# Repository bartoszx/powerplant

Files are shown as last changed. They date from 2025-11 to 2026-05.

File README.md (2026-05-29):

# POWERPANEL

_Opis funkcjonalny systemu — retro‑analogowy interfejs do Home Assistanta._

 

<p align="center">
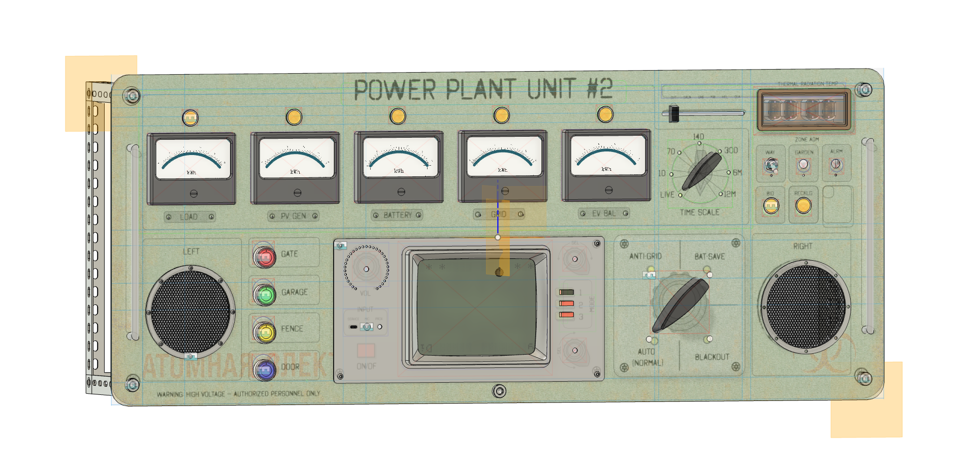
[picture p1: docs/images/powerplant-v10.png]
PowerPanel – wizualizacja
  
  <a href="docs/images/clean-wiz.JPEG">PowerPanel – czysta wizualizacja</a>
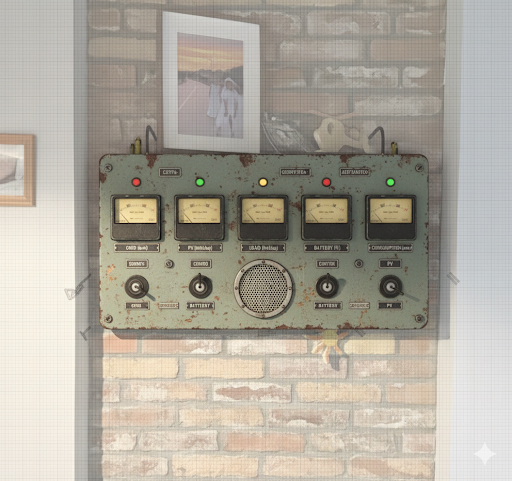
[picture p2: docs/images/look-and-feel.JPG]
PowerPanel – look & feel
  
</p>

_Kliknij, aby powiększyć. Wymiary panelu: 108 × 44 cm._ 

### Spis treści
- [1. Cel i koncepcja projektu](#1-cel-i-koncepcja-projektu)
- [2. Architektura i główne sekcje panelu](#2-architektura-i-główne-sekcje-panelu)
  - [2.1 Płyta główna (Main Board)](#21-płyta-główna-main-board)
  - [2.2 Moduły zewnętrzne](#22-moduły-zewnętrzne)
- [3. Mechanika i interfejs użytkownika](#3-mechanika-i-interfejs-użytkownika)
  - [3.1 Mierniki (sekcja)](#31-mierniki-sekcja)
- [4. Bloki funkcjonalne](#4-bloki-funkcjonalne)
  - [4.1 BLK_METER_ANALOG](#41-blk_meter_analog)
  - [4.2 BLK_METER_LED](#42-blk_meter_led)
  - [4.3 BLK_SWITCHES](#43-blk_switches)
  - [4.4 BLK_CONSOLE](#44-blk_console)
  - [4.5 BLK_SWITCH_LED](#45-blk_switch_led)
- [5. Komunikacja i zasilanie](#5-komunikacja-i-zasilanie)
- [6. Mechanika i ergonomia](#6-mechanika-i-ergonomia)
- [7. Uwagi konstrukcyjne](#7-uwagi-konstrukcyjne)
- [8. Podsumowanie](#8-podsumowanie)
- [9. Pliki schematów i PCB](#9-pliki-schematów-i-pcb)

---

## 1. Cel i koncepcja projektu
PowerPanel to fizyczna interpretacja możliwości systemu Home Assistant — 
czyli materialny, retro-analogowy interfejs do cyfrowego świata automatyki domowej.  

Nie jest to tylko panel energetyczny, ale wielosekcyjny moduł kontrolny i wizualizacyjny,
który odwzorowuje najważniejsze funkcje systemu HA w postaci fizycznych mierników, przycisków, 
przełączników, enkoderów i wskaźników świetlnych.

Celem jest uzyskanie wrażenia „żywego pulpitu sterowniczego” — 
panelu, który reaguje w czasie rzeczywistym na dane z Home Assistanta: energię, temperatury, stany stref, 
tryby pracy, alarmy, a także pozwala na bezpośrednią interakcję z systemem przez dotyk, pokrętła i przełączniki.

Całość utrzymana w stylistyce retro-industrialnej: 
mierniki URAL, bakelitowe przełączniki krzywkowe, suwakowe selektory, 
oraz matowy ekran LCD w stylu terminalowym, wpisujący się w analogowy klimat.

## 2. Architektura i główne sekcje panelu
System składa się z jednej płyty głównej (Main Board) i zestawu płytek peryferyjnych połączonych taśmami IDC.

### 2.1 Płyta główna (Main Board)
Zawiera wszystkie układy logiczne, analogowe i interfejsowe:
- ekspandery MCP23017 (wejścia, przyciski, enkodery),
- przetwornik DAC MCP4728 (sterowanie wskazówkami),
- bufory 74AHCT125 (3.3V → 5V dla WS2812),
- sterowniki ULN2803A (lampki i podświetlenia 12V),
- wzmacniacze LM358 (sterowniki prądowe wskaźników),
- złącza IDC dla modułów zewnętrznych.

<p align="center">
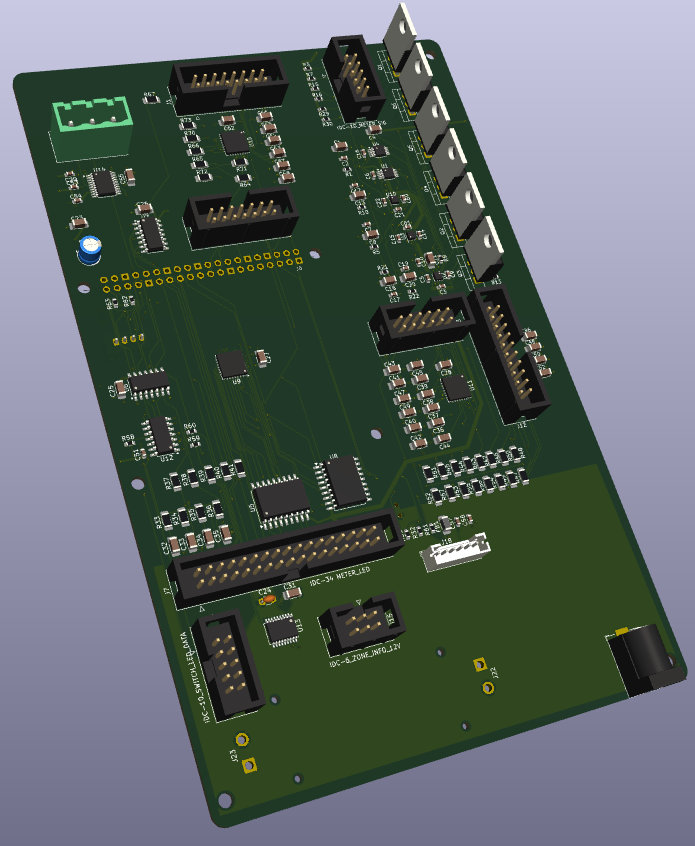
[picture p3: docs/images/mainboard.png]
Płyta główna – wizualizacja 3D
  
</p>

_Wizualizacja 3D płyty głównej (KiCad)._ 

Serce systemu stanowi Raspberry Pi 5, zamontowane bezpośrednio na płycie głównej (formą zbliżone do HAT), zapewniając komunikację, logikę i integrację z Home Assistantem.

Zasilanie:
- 12 V – sekcja mocy i lampek,
- 5 V – LED i DAC,
- 3.3 V – logika i magistrala I²C.
Masę podzielono na GND i GNDPWR (łączone w jednym punkcie).

### 2.2 Moduły zewnętrzne
- **NIXIE BOARD** – sterowanie lampami IN-14 (SPI, wysokonapięciowe).
- **METER PANEL** – z miernikami URAL i podświetleniem LED WS2812.
- **SWITCH PANEL** – sekcja przełączników trybów i zakresów czasowych.
- **CONSOLE PANEL** – centralny moduł z retro-ekranem LCD, enkoderami i kontrolkami.
- **ZONE ADM PANEL** – sekcja administracyjna stref (WAY / GARDEN / ALARM / OPEN).
- **INFO LED BOARD** – lampki 12 V (BIO, REC, OPEN, statusy).

Każdy moduł łączy się z płytą główną przez złącza IDC (10–34 pin).

## 3. Mechanika i interfejs użytkownika
Panel został podzielony na kilka stref funkcjonalnych, rozmieszczonych ergonomicznie na froncie obudowy:

- **Sekcja mierników (górna)** – pięć wskaźników URAL, 
  każdy z osobnym kanałem DAC i LED-podświetleniem.  
  Powyżej nich znajduje się przełącznik krzywkowy pozwalający zmieniać **skalę czasu** (LIVE / 1D / 7D / 14D / 1M / 6M / 12M).

- **Sekcja ZONE ADM (lewa dolna)** – przyciski i lampki strefowe, 
  np. WAY, GARDEN, ALARM, OPEN_PLACE.  
  Każda lampka 12 V jest sterowana z ULN2803A, a przycisk raportuje stan do HA przez I²C.

- **Centralna sekcja sterowania** – retro ekran LCD (terminalowy, tekstowy) 
  pokazujący status systemu i parametry; obok pokrętło **głośności (ENC_VOL)** z ring-LED, 
  przyciski **MODE_A/B/C** (zmiana trybu HA), oraz **przełącznik INPUT/OUTPUT**.

- **Sekcja energetyczna (prawa dolna)** – przełącznik krzywkowy głównego obiegu energetycznego (np. GRID / BAT / ISLAND),
  kontrolki statusu ładowania, oraz wskaźnik prądu zasilania głównego.

- **Selektor temperatury (prawy górny)** – przełącznik suwakowy wybierający, 
  które pomieszczenie ma być aktualnie wskazywane na mierniku temperatury (OUTDOOR / SALON / GAB / MIB / HEL / OLA).

Każdy element panelu ma fizyczne sprzężenie zwrotne: ruch wskazówki, światło LED, dźwięk enkodera, klik przełącznika.  
To czyni PowerPanel prawdziwie materialnym interfejsem Home Assistanta.

### 3.1 Mierniki (sekcja)
<p align="center">
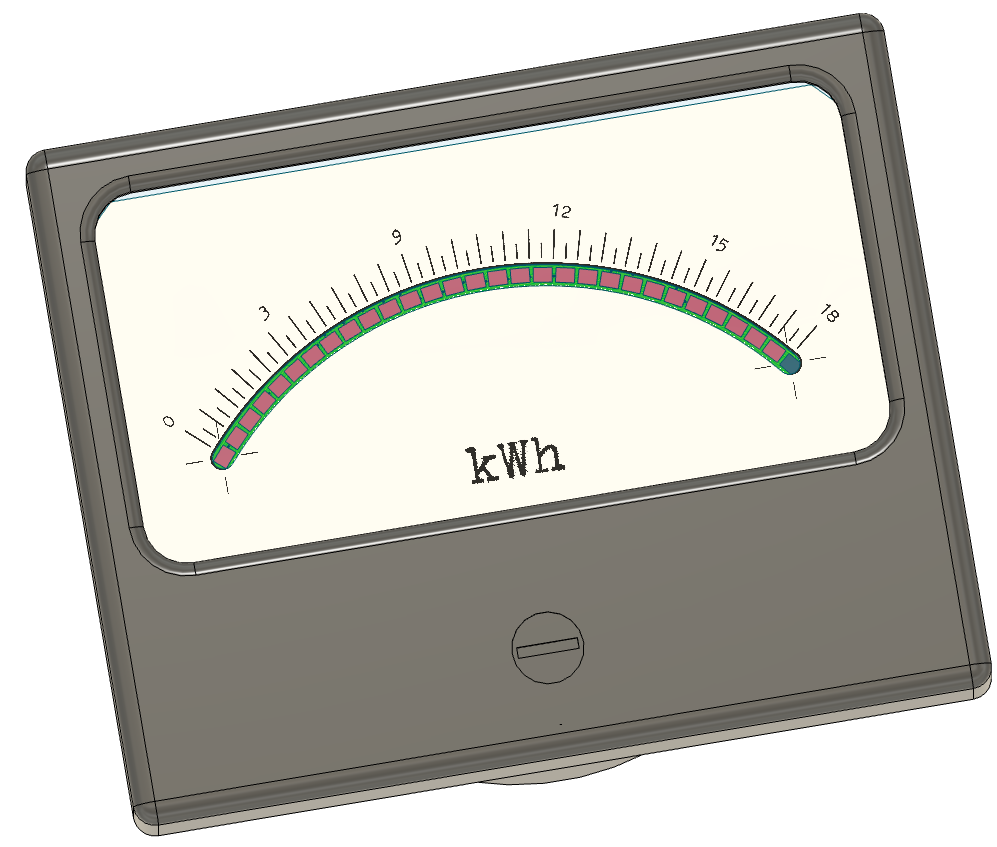
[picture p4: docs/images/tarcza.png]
Tarcza miernika
  
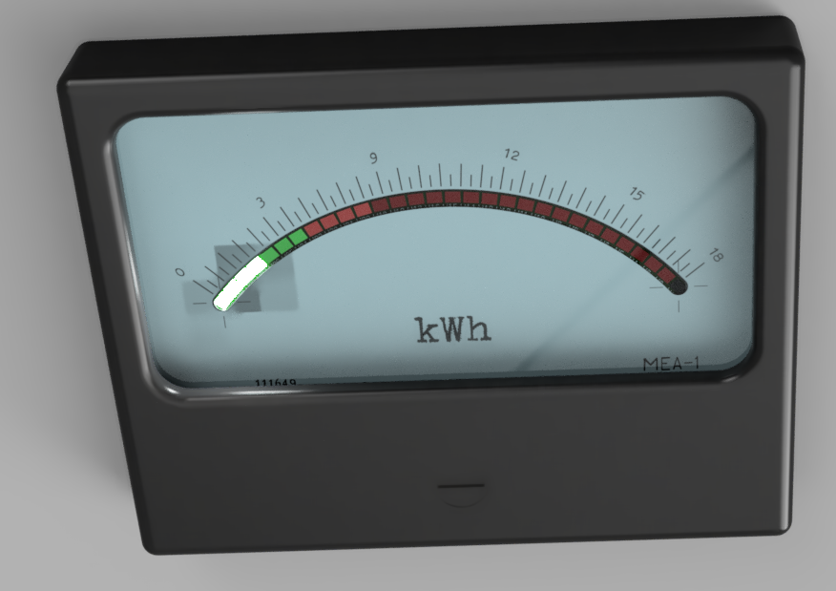
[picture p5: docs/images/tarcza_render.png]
Render sekcji
  
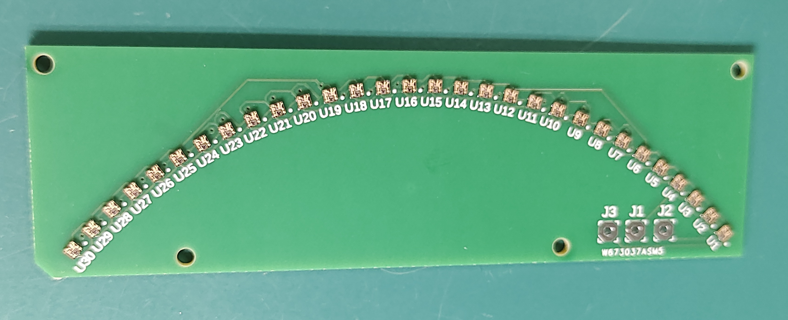
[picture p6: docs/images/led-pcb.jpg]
PCB 30 micro‑LED
  
  
</p>

_Tarcza, render sekcji i płytka z 30 micro‑LED — kliknij, aby powiększyć._

Na schemacie wyjścia prowadzące do poszczególnych mierników oznaczone są ich pierwotnymi parametrami (np. „2A”, „25mA”). Oznaczenia te służą pamięci i kalibracji podczas strojenia układu.

Każdy miernik, poza podstawowym działaniem pomiarowym, został zmodyfikowany:
- pod główną skalą umieszczono 30 programowalnych micro‑LEDów, pozwalających tworzyć efekty świetlne i subtelne wskazania kontekstowe,
- dodatkowy LED podświetla tarczę, poprawiając czytelność w słabym oświetleniu.

## 4. Bloki funkcjonalne

### 4.1 BLK_METER_ANALOG
Sterowanie pięcioma miernikami URAL.  
Układy: MCP4728 + LM358 + tranzystory 2N2222A.  
Każdy kanał DAC generuje napięcie (0–5 V) → LM358 → tranzystor NPN → cewka miernika.  
Filtry RC (100 nF + 10 kΩ) wygładzają wskazanie.  
Zasilanie 5 V, masa GNDPWR.  
Kanały: SENSE_A–E (MTR1–MTR5).

---

### 4.2 BLK_METER_LED
Sterowanie LED WS2812 i przyciskami 12 V w sekcji mierników i przycisków.  
Układy: MCP23017, ULN2803A ×2, 74AHCT125 ×2.  
Port A MCP23017 steruje ULN2803A (OUT_Mx_BL, URAL).  
Port B obsługuje przyciski i kontrolki (BTN_GATE, GARAGE, DOOR itd.).  
Bufory 74AHCT125 translatują sygnały LED 3.3V → 5V (MTR1–MTR5).  
Rezystory 68 Ω w szereg z liniami danych.  
Lampki 12 V sterowane z ULN2803A (open collector).  
GND i GNDPWR łączone w jednym punkcie.

---

### 4.3 BLK_SWITCHES
Sekcja 12 przełączników (tryby + zakresy) i 4 przyciski ZONE ADM.  
Układ: MCP23017 @ 0x21.  
Wejścia z pull-up 10 kΩ, C=100 nF do GND (debounce).  
Złącza:  
- IDC-20_SWITCH_BUS – tryby pracy (AUTO, BAT-SAVE, BLACKOUT, itp.)  
- IDC-12_SWITCH_ZONE_BUS – strefy (WAY, GARDEN, ALARM, OPEN)  
Stany czytane przez I²C.

---

### 4.4 BLK_CONSOLE
Centralny panel z trzema enkoderami i przyciskami MODE.  
Układ: MCP23017 @ 0x23.  
Pull-up 10 kΩ + C=100 nF (debounce).  
Linia INT_CONSOLED (opcjonalne przerwanie).  
Złącze IDC-16_CONSOLE:  
- MODE_A/B/C – wybór trybów  
- ENC_VOL, ENC_TOP, ENC_BOTTOM – enkodery  
- VOL_RING_DATA – dane LED pierścienia  
- przyciski push – w osi enkoderów

---

### 4.5 BLK_SWITCH_LED
Buforowanie danych LED (74AHCT125) i sterowanie lampkami 12 V (ULN2803A).  
Złącza:  
- IDC-10_SWITCH_LED_DATA – LED WS2812  
- IDC-6_ZONE_INFO_12V – lampki BIO / REC / OPEN  
Sygnały 3.3V z RPi → bufory 5V → taśmy WS2812.  
Rezystory R58–R60 = 100 Ω.  
Wspólna masa GND↔GNDPWR.

---

## 5. Komunikacja i zasilanie
Magistrala I²C:
- MCP23017 (SWITCHES) – 0x21  
- MCP23017 (CONSOLE) – 0x23  
- MCP23017 (METER_LED) – 0x20  
- MCP4728 (METER_ANALOG) – 0x60  

Zasilanie:
- +12 V – lampki i przekaźniki  
- +5 V – LED WS2812, DAC  
- +3.3 V – logika i I²C  
- GND / GNDPWR – wspólny punkt (separacja prądów)

---

## 6. Mechanika i ergonomia
- Wskaźniki URAL – analogowe sprzężenie ruchu z DAC.  
- LED – efekt tła i animacje w rytmie danych HA.  
- Przyciski 12 V – kontrola stref / trybów.  
- Enkodery – głośność, tryby, ustawienia.  
- Krzywkowe i suwakowe selektory – wybór skali czasu, temperatury, źródła energii.  
- Retro LCD – dane systemowe i statusy HA.  

- Panel frontowy z blachy stalowej zostanie poddany kontrolowanemu procesowi postarzenia (patyna, przetarcia, delikatnie pordzewiałe krawędzie), aby uzyskać wygląd starego, przemysłowego urządzenia.

Każdy element ma bezpośrednią funkcję w HA i wizualne potwierdzenie akcji.

---

## 7. Uwagi konstrukcyjne
- Separacja GND / GNDPWR.  
- Stitching vias między planami mas.  
- 100 nF przy każdym układzie.  
- Rezystory szeregowe 68–100 Ω przy WS2812.  
- C = 1000 µF przy zasilaniu LED.  
- LM358 i MCP4728 zasilane z 5 V (z odniesieniem do GNDPWR).  
- Bufory 74AHCT125 – VCC = 5 V, Vih ≥ 2 V.

---

## 8. Podsumowanie
PowerPanel to fizyczny interfejs Home Assistanta — 
łączący dane z automatyki, energii, stref, mediów i systemów bezpieczeństwa w jednym, dotykalnym pulpicie.

Zawiera:
- 5 analogowych mierników URAL (DAC-sterowane),
- 3 enkodery + ring LED,
- 20+ LED WS2812,
- 20 przycisków i przełączników,
- kontrolki 12 V,
- wyświetlacz LCD retro,
- oraz krzywkowe i suwakowe selektory trybów.

Stanowi pomost między cyfrowym systemem automatyki a fizycznym światem.

---

## 9. Pliki schematów i PCB

**Źródło prawdy (source of truth)** dla hardware'u: **`hardware/pcb/powerplant.kicad_sch`**.  
Ten plik może się aktualizować; dokumentacja, konfiguracja i kod powinny być z nim zsynchronizowane.

Pliki KiCad znajdują się w katalogu `hardware/pcb`:

- Główne pliki projektu: `hardware/pcb/powerplant.kicad_sch`, `hardware/pcb/powerplant.kicad_pcb`
- Schematy bloków: 
  - `hardware/pcb/BLK_BUTTONS.kicad_sch`
  - `hardware/pcb/BLK_CONSOLE.kicad_sch`
  - `hardware/pcb/BLK_METER_LED.kicad_sch`
  - `hardware/pcb/BLK_SWITCH_LED.kicad_sch`
  - `hardware/pcb/BLK_SWITCHES.kicad_sch`

Pełne drzewo plików sprzętowych: `hardware/pcb/`.

**Moduł sterowania miernikami** (osobny projekt KiCad, pliki w Dropbox: `kicad/powerplant/modul-miernikow.*`):

- Opis schematu (weryfikacja MCP): [`doc/modul-miernikow-opis-schematu.md`](doc/modul-miernikow-opis-schematu.md)
- Wklejka na schemat KiCad: [`doc/modul-miernikow-wklejka-schemat.txt`](doc/modul-miernikow-wklejka-schemat.txt)

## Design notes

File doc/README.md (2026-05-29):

# Dokumentacja modułu mierników

Katalog w repozytorium **powerplant** (`doc/`).

| Plik | Zastosowanie |
|---|---|
| [modul-miernikow-opis-schematu.md](modul-miernikow-opis-schematu.md) | Pełna dokumentacja (czytanie, review, git) |
| [modul-miernikow-wklejka-schemat.txt](modul-miernikow-wklejka-schemat.txt) | Skrót do wklejenia jako blok tekstu na schemacie KiCad |

**Pliki KiCad (źródło prawdy obwodu):**  
`~/Dropbox/kicad/powerplant/modul-miernikow.kicad_pro` (+ `.kicad_sch`, `.kicad_pcb`)

## Weryfikacja przez MCP (KiCAD MCP Server)

Opis obwodu w tych plikach jest uzgadniany z **rzeczywistym schematem** przy użyciu **Model Context Protocol** — serwera MCP podłączonego do KiCad (netlista, ERC/DRC, analiza połączeń).

**Protokół potwierdzania:**

1. Otwarcie / eksport netlisty z aktualnego `modul-miernikow.kicad_sch`.
2. Sprawdzenie połączeń sieci (J18, J1, U16, LM358, AO3400, 74AHCT125).
3. Uruchomienie ERC i DRC (`kicad-cli` lub narzędzia MCP).
4. Wynik weryfikacji wpisywany w sekcji *Weryfikacja MCP* w `modul-miernikow-opis-schematu.md`.

Przy kolejnych zmianach schematu — ponowna weryfikacja MCP i aktualizacja daty w opisie.

**Uwaga:** Stary blok tekstu na schemacie (MCP4728, 2N2222, URAL, GNDPWR) jest **nieważny** — zastąpić treścią z `modul-miernikow-wklejka-schemat.txt`.

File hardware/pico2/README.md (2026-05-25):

# Pico 2 – sterowanie MTR1_DATA z głównego RPi

Pico 2 odbiera komendy po UART od RPi i steruje linią **MTR1_DATA** (WS2812, 34 LEDy) na **GPIO6** oraz podświetleniem na GPIO11..15.

## Połączenia

| RPi (BCM) | Kierunek | Pico 2  | Opis |
|---|---|---|---|
| BCM 14 | TXD → | GPIO 1  | RX (we) |
| BCM 15 | RXD ← | GPIO 0  | TX (wy) |
| GND | | GND | wspólna masa|
| (opcjonalnie 3V3/5V) | | VSYS / VBUS | zasilanie Pico |

**Pico GPIO 6** → **MTR1_DATA** (wejście danych taśmy WS2812 przy mierniku 1).  
**Pico GPIO 11..15** → podświetlenie mierników 1..5 (J5 spare).

## 1. Wgranie MicroPython na Pico 2

1. Pobierz firmware MicroPython dla RP2040:  
   https://micropython.org/download/RPI_PICO2/
2. Przytrzymaj BOOTSEL na Pico, podłącz USB, puść BOOTSEL – pojawi się dysk **RPI-RP2**.
3. Skopiuj na ten dysk plik **`.uf2`** z archiwum – Pico zrestartuje się z MicroPythonem.

## 2. Wgranie programu (main.py)

- Przez **Thonny** (lub inny REPL / mpremote): połącz się z Pico 2 przez USB i wgraj plik **`main.py`** do katalogu głównego (root) urządzenia.
- Albo przez **mpremote** (po `pip install mpremote`):
  ```bash
  mpremote connect /dev/ttyACM0 cp hardware/pico2/main.py :main.py
  mpremote connect /dev/ttyACM0 reset
  ```
- Po wgraniu **main.py** Pico przy starcie uruchomi nasłuch UART i sterowanie LEDami.

## 3. Podłączenie do RPi (bez USB)

- Odłącz Pico od USB.
- Zasil Pico z RPi (3V3 lub 5V – według Twojej konfiguracji) i połącz:
  - RPi **BCM14 (TXD)** → Pico **GPIO1 (RX)**
  - RPi **BCM15 (RXD)** ← Pico **GPIO0 (TX)**
  - **GND** – wspólna masa.
- Włącz RPi; Pico startuje z **main.py** i czeka na dane UART.

## 4. Test z RPi

Na głównym RPi (w katalogu projektu):

```bash
pip install pyserial pyyaml
python3 scripts/test_mtr1_via_pico.py --ping    # test łączności
python3 scripts/test_mtr1_via_pico.py          # miganie 34 LEDów
python3 scripts/test_mtr1_via_pico.py --fill 255 0 0   # cały pasek na czerwono
```

Port UART w configu: **config/hardware.yaml** → **pico2.serial.port** (domyślnie `/dev/serial0`). Na RPi 5 często to `/dev/ttyAMA0` lub symlink `/dev/serial0`.

## Protokół UART (RPi → Pico)

- **0xFF** – ping; Pico odpowiada jednym bajtem **0xFF**.
- **0x01** + **102 bajty** (34 × RGB) – ustawienie kolorów 34 LEDów (łuk) i odświeżenie (show).
- **0x02** + **1 B maska** + **3 B R,G,B** – podświetlenie: maska bit0..4 = MTR1..5 (1=on), kolor z R,G,B. Np. `0x02 0x01 100 180 255` = MTR1, niebiski.
- **0x03** – wszystkie podświetlenia OFF.
- **0x04** + **2 B długość (big-endian)** + **body** – OTA: zapis body do `main.py` na Pico i `soft_reset()` (max 16 KB).

Baud: **115200**, 8N1.

## Kolory (RGB vs GRB)

Większość taśm WS2812 ma **kolejność GRB** na drucie. W **main.py**:
- **Backlight** (GPIO11..15) – zawsze zapis (G,R,B), żeby (255,0,0) z hosta dawało czerwony.
- **Strip łuk** (GPIO6) – stała **MTR1_STRIP_GRB** (domyślnie `True`): host wysyła (R,G,B), Pico zapisuje (G,R,B) do NeoPixel.

Jeśli kolory na łuku się nie zgadzają z tym, co wysyła host (np. czerwony świeci na zielono, lub różne płytki 4-LED zachowują się inaczej), sprawdź:
1. **MTR1_STRIP_GRB** w main.py – ustaw `False`, wgraj OTA i przetestuj. Część taśm to RGB.
2. Jedna fizyczna taśma na wszystkich miernikach – wtedy kolejność jest taka sama; jeśli łączysz różne moduły (np. inne wersje WS2812/SK6812), mogą mieć różny order (RGB/GRB/BGR) i wtedy trzeba osobnej konfiguracji per-pin albo ujednolicić hardware.

## 5. OTA – aktualizacja main.py przez UART (bez USB)

Po **jednorazowym** wgraniu `main.py` przez USB (p. 2) możesz później aktualizować firmware **przez UART** z RPi:

```bash
python3 scripts/ota_pico_main.py
```

Skrypt wysyła zawartość `hardware/pico2/main.py` komendą 0x04. Pico zapisuje ją do `main.py` i restartuje się. Port z configu: **config/hardware.yaml** → **pico2.serial.port**.

**Uwaga:** Pierwsze wgranie `main.py` musi być przez USB (Thonny lub `mpremote cp ... :main.py`), żeby na Pico był kod z obsługą OTA. Potem aktualizacje możesz robić tylko przez UART.

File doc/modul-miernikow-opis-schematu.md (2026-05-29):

# Moduł sterowania miernikami — opis schematu

**Projekt KiCad:** `modul-miernikow.kicad_pro`  
**Pliki KiCad:** `~/Dropbox/kicad/powerplant/`  
**Dokumentacja (git):** `powerplant/doc/` (ten katalog)  
**Skrót do schematu:** [modul-miernikow-wklejka-schemat.txt](modul-miernikow-wklejka-schemat.txt)

---

## Weryfikacja MCP (KiCAD MCP Server)

Ten dokument opisuje **aktualny schemat**, nie historyczny blok tekstu (MCP4728 / 2N2222 / URAL).

| Pole | Wartość |
|---|---|
| Metoda | Model Context Protocol — KiCAD MCP Server + `kicad-cli` |
| Źródło prawdy | `modul-miernikow.kicad_sch`, netlista, ERC/DRC |
| Zakres | Połączenia J18, J1, U16, LM358, AO3400, 74AHCT125; mapa DAC; brak zwarcia nazw sieci krytycznych |
| Ostatnia weryfikacja | 2026-05-25 |
| DRC | 0 naruszeń (`modul-miernikow.kicad_pcb`) |
| ERC | 12 ostrzeżeń (biblioteka LM358, etykiety ML vs `J_METER_PLUS_MINUS+`, global/local labels) — **0 błędów** |
| Potwierdzenie toru A | Wizualnie w KiCad zgodne z opisem poniżej (użytkownik) |

**Przy zmianie schematu:** ponów eksport netlisty, ERC/DRC przez MCP lub `kicad-cli`, zaktualizuj tabelę powyżej i [modul-miernikow-wklejka-schemat.txt](modul-miernikow-wklejka-schemat.txt).

---

## 1. Rola modułu

Moduł **nie** jest pojedynczym miernikiem. To **jedna płyta** obsługująca **wszystkie 5 mierników** oraz komunikująca się z **płytą główną** (RPi5, Pico, przetwornica buck).

Na każdy miernik wychodzi osobny przewód (GX8 → terminal → moduł miernika), agregowany na płytce modułu w złączu **IDC-34 (J1)**.

Każdy miernik ma:

- sterowanie wskazówką (cewka),
- zasilanie i sterowanie LEDów sekcji: **DATA_LIGHT**, **DATA_SCALE**, **DATA_MODE** (w schemacie sieci `MTR_KWH_*` / `GPIO_KWH_*`).

---

## 2. Architektura połączeń

```text
Płyta główna (RPi5, Pico, buck)
        │
        ├── J18 EDGE 2×12 ── +5V, +12V, GND, I2C_SDA/SCL, GPIO_LIGHT/SCALE/KWH
        │                      │
        │                      ▼
        │              [ moduł mierników ]
        │                 U16 DAC7578
        │                 U2,U3,U10 LM358 + Q7..Q12 AO3400
        │                 U1,U4..U7 74AHCT125
        │
        └── (masa wspólna z modułem)

        J1 IDC-34 ──► mierniki 1..5 (cewka + LED DATA + +5V/GND)
```

**Założenie dokumentacyjne:** wszystko, co jest na **J18**, ma kontynuację na płycie głównej (zasilanie, I²C, GPIO).

**J1** to wyłącznie **wyjście na wiązki mierników** w terenie.

---

## 3. Złącza

### J18 — `EDGE` (2×12, do płyty głównej)

| Pin J18 | Sieć | Funkcja |
|---|---|---|
| 1, 2 | +5V | Zasilanie logiki |
| 3, 4, 6, 24 | GND | Masa |
| 5 | +12V | Zasilanie toru analogowego (cewki) |
| 7 | I2C_SDA | → U16 DAC7578 |
| 8 | I2C_SCL | → U16 DAC7578 |
| 9 | GPIO_LIGHT_1 | → U1 (74AHCT) |
| 10 | GPIO_SCALE_1 | → U1 |
| 11 | GPIO_KWH_1 | → U1 |
| 12–23 | GPIO_* 2..5 | → U4, U5, U6, U7 |

### J1 — `IDC-34_METER_SIG_OUT` (2×17, do mierników)

Patrz sekcja 7 i plik [modul-miernikow-wklejka-schemat.txt](modul-miernikow-wklejka-schemat.txt).

**+12 V nie występuje na J1** — cewki zasilane z modułu przez rezystory limitujące od szyny +12 V (wejście +12 V z J18).

---

## 4. Układy scalone

| Ref | Typ | Ilość | Funkcja |
|-----|-----|---|---|
| U16 | DAC7578xPW | 1 | 8-kanałowy DAC, I²C, sterowanie napięciem torów wskazówki |
| U2, U3, U10 | LM358 | 3 | Wzmacniacze — po 2 kanały na układ |
| Q7–Q12 | AO3400A | 6 | N-MOSFET low-side, przełączanie zwrotu cewki |
| U1, U4, U5, U6, U7 | 74AHCT125 | 5 | Bufor 3-state, LED DATA → J1 |

**Nie używane:** MCP4728, tranzystory NPN 2N2222, ULN2803/URAL w tym module.

---

## 5. Tor analogowy — wskazówka

### Wzorzec (kanały A–E2)

```text
DAC7578 VOUTx
    │
    R 10 kΩ
    ├── VIN_FILT_x ──► (+) wejście LM358
    └── 4,7 µF + 100 nF ──► GND

LM358 (−) ◄── SENSE_x ◄── source AO3400
              └── C ~680 pF (między wyjściem opampa a SENSE)
              └── R_SENSE do GND (wartość zależna od kanału)

LM358 wyjście ── R 100 Ω ── bramka AO3400 (Rgate)
                      └── Rpd 100 kΩ do GND

+12 V ── Rlimit ──► J1 "+" (strona cewki w mierniku)
AO3400 drain ──► J1 zwrot ("-" / ML / MR)
```

### Mapowanie DAC → miernik

| Kanał | DAC U16 | Sieć filtra | MOSFET | J1 | Typ miernika |
|---|---|---|---|-----|---|
| A | VOUTA (4) | VIN_FILT_A | Q7 | 1 (+), 2 (−) | jednostronny, 25 µA |
| B | VOUTB (13) | VIN_FILT_B | Q8 | 3 (+), 4 (−) | jednostronny, 5 mA |
| C | VOUTC (5) | VIN_FILT_C | Q9 | 5 (+), 6 (−) | jednostronny, 1 A |
| D | VOUTD (12) | VIN_FILT_D | Q10 | 7 (+), 8 (−) | jednostronny, TBC |
| E1 (ML) | VOUTE (6) | VIN_FILT_E1 | Q11 | 9 (ML) | ± lewo |
| E2 (MR) | VOUTF (11) | VIN_FILT_E2 | Q12 | 10 (MR) | ± prawo |

- **ML** = Miernik Left  
- **MR** = Miernik Right  
- Na fragmencie schematu może występować też etykieta `J_METER_PLUS_MINUS+` — **ta sama sieć co ML** (ERC: unikać duplikacji nazw).

**Nieużywane wyjścia DAC:** VOUTG, VOUTH (NC).

**LDAC (U16 pin 1) → GND** — aktualizacja wyjść DAC bez osobnego strobe.  
**ADDR0 (U16 pin 2) → GND** — bit adresu I²C (pełny adres w datasheet + kod Pico).

### Rezystory SENSE (kalibracja)

| Kanał | RSENSE (do GND z SENSE) | Uwaga |
|---|---|---|
| A | 200 kΩ | bias / słaba pętla prądowa w klasycznym sensie |
| B | 140 kΩ | jw. |
| C | 500 Ω | |
| D | 200 kΩ | |
| E1, E2 | 820 Ω | sensowniejszy zwrot dla ± |

Kalibracja prądu cewki **per kanał** w firmware i przy bring-up.

### Miernik ± (środek wskazówki)

- **4 mierniki** — wychylenie jednostronne (A–D).  
- **1 miernik** — wychylenie **+ / −** od środka: osobno **ML** i **MR**, dwa kanały DAC i dwa MOSFETy.  
- R29, R30 = **10 Ω** do +12 V (inna skala niż Rlimit 100 kΩ na torach A–D).

---

## 6. Tor LED

```text
Pico GPIO (J18) → wejście 74AHCT125 → wyjście → R 68 Ω → J1 MTR_* → miernik
```

| Miernik | LIGHT | SCALE | MODE (KWH) |
|---|---|---|---|
| 1 | J1-11 | J1-12 | J1-13 |
| 2 | J1-14 | J1-15 | J1-16 |
| 3 | J1-17 | J1-18 | J1-19 |
| 4 | J1-20 | J1-21 | J1-22 |
| 5 | J1-23 | J1-24 | J1-25 |

Zasilanie LED w miernikach: **+5 V** (J1: 27, 29, 31, 33), **GND** (26, 28, 30, 32, 34).

### 74AHCT125 — OE i kierunek

- **VCC = 5 V**  
- Kierunek: **host → bufor → J1** (Pico na płycie głównej steruje wejściami A)  
- **OE aktywne LOW:** kanał 1 OE (pin 1) → +5 V (**wyłączony**); OE kanałów 2–4 → GND (**włączone**)  
- Nieużywane piny 2–3 (1A, 1Y) — `no_connect`

---

## 7. Pełna mapa J1 (IDC-34)

| Pin | Sieć | Opis |
|-----|---|---|
| 1 | J_METER_25uA+ | + cewka, kanał A |
| 2 | METER- | zwrot Q7 |
| 3 | J_METER_5mA+ | + cewka, kanał B |
| 4 | (zwrot Q8) | − cewka B |
| 5 | J_METER_1A+ | + cewka, kanał C |
| 6 | (zwrot Q9) | − cewka C |
| 7 | J_METER_TBC+ | + cewka, kanał D |
| 8 | (zwrot Q10) | − cewka D |
| 9 | ML / J_METER_PLUS_MINUS+ | + strona ± |
| 10 | MR | − strona ± (Q12) |
| 11–25 | MTR_LIGHT/SCALE/KWH 1..5 | LED po buforze |
| 26–34 | GND / +5V | zasilanie szynowe mierników |

---

## 8. Zasilanie i masa

| Szyna | Źródło | Konsumenci na module |
|---|---|---|
| +5V | J18 | DAC, 74AHCT, kondensatory odsprzęgania |
| +12V | J18 pin 5 | Rlimit cewek, LM358 (pin 8), kondensatory C3/C4… |
| GND | J18 + J1 | wspólna masa analog + cyfra |

**GNDPWR** — nie występuje; jedna sieć **GND**.

---

## 9. Odsprzęganie (skrót)

- Każdy kanał DAC: **10 kΩ + 4,7 µF + 100 nF** do GND.  
- +12 V: **100 nF + 10 µF** (C3, C4, …).  
- DAC U16 i 74AHCT: grupa kondensatorów przy **+5 V** (C16, C55, C56, C74–C83).  
- LM358: **~680 pF** między wyjściem a SENSE (stabilizacja pętli).

---

## 10. PCB (stan na dzień weryfikacji MCP)

- Wymiary płyty: ~121 × 68 mm  
- DRC: **0** naruszeń  
- Via: drill 0,3 mm / 0,6 mm — nadaje się do ręcznego przewlekania  
- **Test points:** TP1–TP14 na schemacie (sekcja poniżej); footprint `TestPoint_Pad_D1.0mm` — po **Update PCB** (F8)

### Test points (TP1–TP14)

Panel po lewej stronie schematu (etykieta „TEST POINTS”); footprint: `TestPoint:TestPoint_Pad_D1.0mm`.

| Ref | Sieć | Ref | Sieć |
|-----|---|-----|---|
| TP1 | VIN_FILT_A | TP8 | SENSE_B |
| TP2 | VIN_FILT_B | TP9 | SENSE_C |
| TP3 | VIN_FILT_C | TP10 | SENSE_D |
| TP4 | VIN_FILT_D | TP11 | SENSE_E1 |
| TP5 | VIN_FILT_E1 | TP12 | SENSE_E2 |
| TP6 | VIN_FILT_E2 | TP13 | +5V |
| TP7 | SENSE_A | TP14 | +12V |

---

## 11. Bring-up (po wytrawieniu płytki)

Kolejność pierwszego uruchomienia na stole:

1. Zasilanie J18 (+5 V, +12 V, GND) — bez zwarcia.  
2. I²C — wykrycie DAC7578, odczyt rejestru.  
3. Kanał A — mały kod DAC, pomiar `VIN_FILT_A`, opcjonalnie cewka / obciążenie zamiast miernika.  
4. Kanały B, C, D po kolei.  
5. ± ML / MR — osobno E1 i E2.  
6. Jedna linia LED (np. `MTR_LIGHT_1`).  
7. Podłączenie J1 → 5 mierników.

---

## 12. Historia zmian dokumentacji

| Data | Zmiana |
|---|---|
| 2026-05-25 | Utworzenie w `powerplant/doc/`; weryfikacja MCP; zastąpienie opisu MCP4728/URAL/NPN |
| 2026-05-25 | TP1–TP14 na schemacie (VIN_FILT, SENSE, +5V, +12V) |

---

## Powiązane pliki

- [README.md](README.md) — ten katalog  
- [modul-miernikow-wklejka-schemat.txt](modul-miernikow-wklejka-schemat.txt) — wklejka na schemat KiCad

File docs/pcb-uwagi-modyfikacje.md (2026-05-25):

# Uwagi i planowane modyfikacje PCB (BLK_METER_LED, złącza)

Plik zbiera wymagania i uwagi do kolejnej rewizji płytki / zmian w okablowaniu.

---

## 1. MCP23017 – adresy I²C i sterowanie 5 miernikami

**Problem:** Rozszerzacze I/O (MCP23017) mają ten sam adres I²C, przez co nie da się niezależnie sterować wszystkimi 5 miernikami.

**Wymaganie:** Zmienić podejście do MCP tak, aby:
- każdy miernik (MTR1..MTR5) mógł być sterowany osobno,
- na I²C były unikalne adresy (np. różne A0/A1/A2 lub osobne układy z różnymi adresami).

**Uwagi do projektu:** Sprawdzić schemat BLK_METER_LED – które MCP sterują OUT_Mx_BL / OUT_Mx_URAL; zaproponować nowy podział adresów (np. 0x20, 0x21, …) i ewentualnie dodatkowe piny adresowe na PCB.

---

## 2. Jedno złącze na obsługę wszystkich mierników (wskaźówka + LED)

**Problem:** Obecnie sygnały są rozbite na wiele złączy – wskaźówka (DAC/cewka) w jednym, dane LED (MTRx_DATA) w innym, podświetlenie (J5 spare) osobno itd.

**Wymaganie:** Jedno gniazdo (lub jeden zestaw złączy) do obsługi wszystkich mierników:
- wskaźówka (analog / DAC),
- LED (łuk / pasek WS2812),
- podświetlenie (WS2812),

tak aby jeden kabel / jedna wtyczka obsługiwała cały miernik (albo wszystkie mierniki z jednego, czytelnego złącza).

**Uwagi do projektu:** Zdefiniować pinout tego złącza (zasilanie, GND, DATA_WS2812, DAC/cewka, ewent. wspólne linie) i przenieść go na PCB zamiast rozproszonych J5/MTRx_DATA itd.

---

## 3. Podświetlenie miernika – z LED na programowalne (WS2812)

**Stan:** Podświetlenie miernika zostało zmienione ze zwykłego LED na taśmę/pasek programowalny (WS2812).

**Konsekwencje:**
- Sterowanie jest przez linię danych (np. Pico GPIO11..15 → J5 spare), nie przez proste ON/OFF z MCP (OUT_Mx_BL).
- W firmware (Pico `main.py`): BACKLIGHT_PINS = [11, 12, 13, 14, 15], BACKLIGHT_LED_COUNTS (np. 2, 2, 40, 40, 40).
- Na PCB: sygnały podświetlenia to MTRx_DATA (lub odpowiedniki na J5), buforowane 3.3 V → 5 V (74AHCT125), z rezystorami szeregowymi (np. 68 Ω).

**Uwagi do projektu:** W następnej wersji PCB:
- potwierdzić, że podświetlenie jest wyłącznie WS2812 (bez równoległego sterowania przez MCP OUT_Mx_BL, chyba że celowo zostawione jako enable),
- ewentualnie uprościć opis w schemacie („podświetlenie = WS2812”) i dopasować nazewnictwo netów/złączy.

---

## Podsumowanie

| # | Temat | Cel |
|---|---|-----|
| 1 | MCP23017 | Unikalne adresy I²C, sterowanie 5 miernikami |
| 2 | Złącza | Jedno gniazdo na miernik (wskaźówka + LED + podświetlenie) |
| 3 | Podświetlenie | Ujęcie w dokumentacji przejścia z LED na WS2812 |

---

*Ostatnia aktualizacja: na podstawie uwag użytkownika.*

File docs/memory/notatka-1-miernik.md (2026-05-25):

# 📝 MCP4728 + analogowe mierniki  
**Projekt:** POWERPLANT / smartgun  
**Data:** 2026-02-08  

---

## 1. Konfiguracja sprzętowa
- DAC: **MCP4728**
- Adres I²C: **stały 0x60**
- Brak pinów adresowych (A0/A1) → brak możliwości zmiany adresu
- Zasilanie DAC: **~5 V**
- Wyjścia:
  - **VOUTA–D → LM358 → IRLZ44N → cewka miernika → Rsense → GND**
- Liczba mierników: **5**
  - 4 obsługiwane przez MCP4728
  - 5-ty wymaga osobnego rozwiązania

---

## 2. Kluczowe ustalenia
### ❌ Zmiana adresu MCP4728
- Nie da się zmienić adresu:
  - software’owo
  - przez EEPROM
  - przez LDAC / General Call
- Adres **0x60 jest zaszyty w krzemie**
- Wariant użyty na PCB **nie posiada pinów A0/A1**

➡️ **Dwa MCP4728 na jednej magistrali I²C bez muxa są niemożliwe**

---

## 3. Problemy początkowe i ich przyczyna
### 3.1 Zapis do DAC
- Biblioteka `adafruit_mcp4728` działała poprawnie
- Własny skrypt nie działał, ponieważ:
  - używał `SMBus.write_i2c_block_data()`
  - MCP4728 **nie obsługuje SMBus block write**
- Układ wymaga **RAW I²C (`i2c_rdwr`)**

➡️ Rozwiązanie: użycie **surowego zapisu I²C**

---

### 3.2 Ograniczenie napięcia do ~2 V
- MCP4728 miał zapisane w EEPROM:
  - **VREF = internal 2.048 V**
  - **GAIN = x1**
- Tryb Fast Write **nie zmienia VREF/GAIN**

➡️ Rozwiązanie:
- użycie **Multi-Write Input Register (0x40)**
- ustawienie:
  - `VREF = internal`
  - `GAIN = x2`

➡️ Efekt:
- **pełna skala ~4.9 V na VOUT**

---

## 4. Finalna konfiguracja DAC (działająca)
- Skala: **0–4095**
- Konfiguracja:
  - `VREF = internal`
  - `GAIN = x2`
- Efektywne napięcie wyjściowe: **~0–5 V**
- Uznana jako konfiguracja docelowa

---

## 5. Diagnostyka toru miernika
### Punkty pomiarowe
- **VOUTA MCP4728**  
  - stabilne napięcie DC  
  - poprawna praca DAC
- **Wyjście do miernika (IDC-10)**  
  - skoki napięcia  
  - overshooty  
  - wartości > VREF

➡️ Jest to **normalne**, ponieważ:
- miernik = indukcyjność
- pętla: LM358 + MOSFET + cewka
- brak tłumienia powoduje oscylacje
- multimetr pokazuje wartości uśrednione

---

## 6. Wnioski sprzętowe
- DAC działa poprawnie
- Oprogramowanie działa poprawnie
- MOSFET (IRLZ44N) działa poprawnie
- Miernik reaguje

❗ Główny problem: **niestabilna pętla prądowa**

---

## 7. Zalecane poprawki hardware
1. **Dioda flyback** równolegle do cewki miernika  
   (np. 1N4148 / dioda Schottky)
2. **Kondensator filtrujący na SENSE_A → GND**
   - start: **100 nF**
   - w razie potrzeby: 220–470 nF
3. Opcjonalnie:
   - RC na Gate MOSFETa (np. 10–47 nF)

---

## 8. Zalecenia software
- Nie używać pełnej skali 0–4095
  - typowo: **0–600 / 0–1200**
- Wolne rampy:
  - `step = 5–10`
  - `delay = 20–30 ms`
- Miernik analogowy ma wolną mechanikę

---

## 9. Problem 5. miernika – decyzje architektoniczne
Ponieważ:
- MCP4728 ma **tylko jeden adres (0x60)**
- liczba mierników > liczba kanałów DAC

### Realne opcje:
1. ✅ **I²C multiplexer TCA9548A**
2. ✅ **PWM + filtr RC** dla 5-tego miernika
3. ❌ Zmiana adresu MCP4728 (niemożliwe)

---

## 10. Stan końcowy
- Układ działa poprawnie
- Skala DAC opanowana
- Przyczyna problemów zidentyfikowana
- Projekt gotowy do dalszej rozbudowy

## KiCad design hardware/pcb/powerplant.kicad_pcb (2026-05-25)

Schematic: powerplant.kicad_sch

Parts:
A1: RaspberryPi_Pico; RaspberryPi_Pico_Common_Unspecified
C1, C8, C11, C13, C18, C20: 4.7 µF; R_1206_3216Metric
C2, C3, C6, C7, C10, C12, C16, C17, C19, C59, C60, C61: 100 nF; C_0603_1608Metric
C4, C29: 10 µF; R_1206_3216Metric
C5, C9, C14, C15, C21, C22: 680 pF; C_0603_1608Metric
C53, C58: 1 µF; C_0603_1608Metric
C54: 4.7 µF; C_0603_1608Metric
FB2: FerriteBead 600 Ω @ 100 MHz; L_1206_3216Metric_Pad1.22x1.90mm_HandSolder
J2: J_AUX; JST_PH_B8B-PH-K_1x08_P2.00mm_Vertical
J3: VL53L0X; JST_PH_B4B-PH-K_1x04_P2.00mm_Vertical
J4: J_LCD_PWR; JST_PH_B2B-PH-K_1x02_P2.00mm_Vertical
J5: SPARE; JST_PH_B8B-PH-K_1x08_P2.00mm_Vertical
J6: RPi_GPIO; RPI_Hat_B_NOPCB
J16: 14_NIXIE_BUS; IDC-Header_2x07_P2.54mm_Vertical
J19: J_LIGHT; JST_PH_B4B-PH-K_1x04_P2.00mm_Vertical
J21: IDC-10_METER_SIG; IDC-Header_2x05_P2.54mm_Vertical
J22: J_IN; SolderWire-1sqmm_1x02_P5.4mm_D1.4mm_OD2.7mm
J23: J_OUT; SolderWire-1sqmm_1x02_P5.4mm_D1.4mm_OD2.7mm
J24: POWER IN 12V; BarrelJack_Horizontal
NT1: NetTie_2; NetTie-2_THT_Pad1.0mm
Q1, Q2, Q3, Q4, Q5, Q6: IRLZ44N; TO-220-3_Vertical
R1, R5, R9, R10, R21, R22: 10 kΩ; R_0603_1608Metric
R2, R6, R11, R12, R23, R24: 100 Ω; R_1206_3216Metric_Pad1.30x1.75mm_HandSolder
R3, R15: Rlimit 100 kΩ; R_0603_1608Metric
R4, R8, R13, R14, R25, R26: Rpd 100 kΩ; R_0603_1608Metric
R7: Rlimit 150 kΩ; R_0603_1608Metric
R16, R29, R30: Rlimit 10 Ω; R_0603_1608Metric
R17, R20: RSENSE 200 kΩ; R_0603_1608Metric
R18: RSENSE 140 kΩ; R_0603_1608Metric
R19: RSENSE 500 Ω; R_0603_1608Metric
R27, R28: RSENSE 820 Ω; R_0603_1608Metric
R62, R63: 4.7kΩ; R_0603_1608Metric
U1, U4: MCP4728; MSOP-10_3x3mm_P0.5mm
U2, U3, U10: LM358_DFN; DFN-8-1EP_2x2mm_P0.5mm_EP1.05x1.75mm
U14: TPS22917DBV; SOT-23-6

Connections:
+3.3V: FB2.1, J5.1, J6.1 (3.3V), R62.1, R63.1; also elsewhere on the board
+5V: A1.40 (VBUS), C6.2, C16.2, C53.2, J3.4, J6.2 (5V), J16.1, J16.10, J23.1, U1.1 (VDD), U4.1 (VDD), U14.1 (VIN); also elsewhere on the board
+12V: C3.1, C4.1, C29.1, C60.1, C61.1, J22.1, J24.1, R3.1, R7.1, R15.1, R16.1, R29.2, R30.2, U2.8 (V+), U3.8 (V+), U10.8 (V+); also elsewhere on the board
/AUX_I2S_LRCLK: J2.2, J6.35 (BCM19_MISO_PCM_FS)
/AUX_I2S_RX: J2.4, J6.38 (BCM20_MOSI_PCM_DI)
/AUX_I2S_TX: J2.3, J6.40 (BCM21_SCLK_PCM_DO)
/AUX_SCL: J2.6, J3.2, J6.5 (BCM3_SCL), J19.4, R62.2, U1.2 (SCL), U4.2 (SCL); also elsewhere on the board
/AUX_SDA: J2.5, J3.3, J6.3 (BCM2_SDA), J19.3, R63.2, U1.3 (SDA), U4.3 (SDA); also elsewhere on the board
/BLK_CONSOLE/INT_CONSOLE: J6.21 (BCM9_MISO); also elsewhere on the board
/BLK_METER_LED/CTRL_GARAGE_LED: J6.16 (BCM23); also elsewhere on the board
/BLK_METER_LED/CTRL_GATE_LED: J6.18 (BCM24); also elsewhere on the board
/BLK_METER_LED/GPIO_LED1: A1.9 (GPIO6); also elsewhere on the board
/BLK_METER_LED/GPIO_LED2: A1.10 (GPIO7); also elsewhere on the board
/BLK_METER_LED/GPIO_LED3: A1.11 (GPIO8); also elsewhere on the board
/BLK_METER_LED/GPIO_LED4: A1.12 (GPIO9); also elsewhere on the board
/BLK_METER_LED/GPIO_LED5: A1.14 (GPIO10); also elsewhere on the board
/BLK_METER_LED/GPIO_VOL_RING: A1.7 (GPIO5); also elsewhere on the board
/BLK_SWITCH_LED/LED_MODE_DATA_IN: A1.5 (GPIO3); also elsewhere on the board
/BLK_SWITCH_LED/LED_RANGE_DATA_IN: A1.4 (GPIO2); also elsewhere on the board
/BLK_SWITCH_LED/LED_TEMP_DATA_IN: A1.6 (GPIO4); also elsewhere on the board
/CTRL_INFO_BIO: J6.15 (BCM22); also elsewhere on the board
/CTRL_INFO_OPEN: J6.11 (BCM17); also elsewhere on the board
/CTRL_INFO_REC: J6.13 (BCM27); also elsewhere on the board
/GP0_TX_PICO: A1.1 (GPIO0), J6.10 (BCM15_RXD)
/GP1_RX_PICO: A1.2 (GPIO1), J6.8 (BCM14_TXD)
/GP11: A1.15 (GPIO11), J5.3
/GP12: A1.16 (GPIO12), J5.4
/GP13: A1.17 (GPIO13), J5.5
/GP14: A1.19 (GPIO14), J5.6
/GP15: A1.20 (GPIO15), J5.7
/GP16: A1.21 (GPIO16), J5.8
/J_METER_1A+: J21.5, R15.2
/J_METER_5mA+: J21.3, R7.2
/J_METER_25uA+: J21.1, R3.2
/J_METER_PLUS_MINUS+: J21.9, Q5.2 (D), R29.1
/J_METER_TBC+: J21.7, R16.2
/LCD_PWR_EN: J6.12 (BCM18_PCM_C), U14.3 (ON)
/METER-: J21.2, Q1.2 (D)
/MR: J21.10, Q6.2 (D), R30.1
/NIXIE_CS1: J6.24 (BCM8_CE0), J16.5
/NIXIE_CS2: J6.26 (BCM7_CE1), J16.6
/NIXIE_CS3: J6.22 (BCM25), J16.7
/NIXIE_CS4: J6.27 (BCM0_ID_SD), J16.8
/SENSE_A: C5.2, Q1.3 (S), R17.2, U2.2 (-)
/SENSE_B: C9.2, Q2.3 (S), R18.2, U2.6 (-)
/SENSE_C: C14.2, Q3.3 (S), R19.2, U3.2 (-)
/SENSE_D: C15.2, Q4.3 (S), R20.2, U3.6 (-)
/SENSE_E1: C21.2, Q5.3 (S), R27.1, U10.2 (-)
/SENSE_E2: C22.2, Q6.3 (S), R28.1, U10.6 (-)
/SPI_MOSI: J6.19 (BCM10_MOSI), J16.3
/SPI_SCLK: J6.23 (BCM11_SCLK), J16.4
/VIN_FILT_A: R1.1, U1.6 (VOUTA), U2.3 (+)
/VIN_FILT_B: R5.1, U1.7 (VOUTB), U2.5 (+)
/VIN_FILT_C: R9.1, U1.8 (VOUTC), U3.3 (+)
/VIN_FILT_D: R10.1, U1.9 (VOUTD), U3.5 (+)
/VIN_FILT_E1: R21.1, U4.6 (VOUTA), U10.3 (+)
/VIN_FILT_E2: R22.1, U4.7 (VOUTB), U10.5 (+)
GND: A1.3 (GND), A1.8 (GND), A1.13 (GND), A1.18 (GND), A1.23 (GND), A1.28 (GND), A1.38 (GND), C6.1, C16.1, C53.1, C54.2, C58.1, C59.1, J2.7, J3.1, J4.2, J5.2, J6.39 (GND), J16.2, J16.11, J16.12, J19.2, J23.2, NT1.1, U1.10 (VSS), U4.10 (VSS), U14.2 (GND); also elsewhere on the board
GNDPWR: C1.2, C2.1, C3.2, C4.2, C7.1, C8.2, C10.1, C11.2, C12.1, C13.2, C17.1, C18.2, C19.1, C20.2, C29.2, C60.2, C61.2, J22.2, J24.2, NT1.2, R4.2, R8.2, R13.2, R14.2, R17.1, R18.1, R19.1, R20.1, R25.1, R26.1, R27.2, R28.2, U2.4 (V-), U2.9 (PAD), U3.4 (V-), U3.9 (PAD), U10.4 (V-), U10.9 (PAD); also elsewhere on the board
unnamed: C1.1, C2.2, R1.2
unnamed: C5.1, R2.1, U2.1
unnamed: C7.2, C8.1, R5.2
unnamed: C9.1, R6.1, U2.7
unnamed: C10.2, C11.1, R9.2
unnamed: C12.2, C13.1, R10.2
unnamed: C14.1, R11.1, U3.1
unnamed: C15.1, R12.1, U3.7
unnamed: C17.2, C18.1, R21.2
unnamed: C19.2, C20.1, R22.2
unnamed: C21.1, R23.1, U10.1
unnamed: C22.1, R24.1, U10.7
unnamed: C54.1, J4.1, U14.6 (VOUT)
unnamed: C58.2, C59.2, FB2.2, J19.1
unnamed: J21.4, Q2.2 (D)
unnamed: J21.6, Q3.2 (D)
unnamed: J21.8, Q4.2 (D)
unnamed: Q1.1 (G), R2.2, R4.1
unnamed: Q2.1 (G), R6.2, R8.1
unnamed: Q3.1 (G), R11.2, R13.1
unnamed: Q4.1 (G), R12.2, R14.1
unnamed: Q5.1 (G), R23.2, R25.2
unnamed: Q6.1 (G), R24.2, R26.2

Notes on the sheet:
⚙️ BLK_METER_ANALOG - opis funkcjonalny ======================================== Sekcja: Tory sterowania i pomiaru wskaźników analogowych (5 kanałów VU / mA / wskazówki URAL) Układy główne: U3A-U3E, U10A-U10C - LM358 (wzmacniacze operacyjne) U1 - MCP4728 (4-kanałowy DAC I²C, 12-bit) Q1-Q5 - tranzys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
CZUJNIK SWIATLA
NIXIE zew board https://github.com/dekuNukem/exixe po SPI

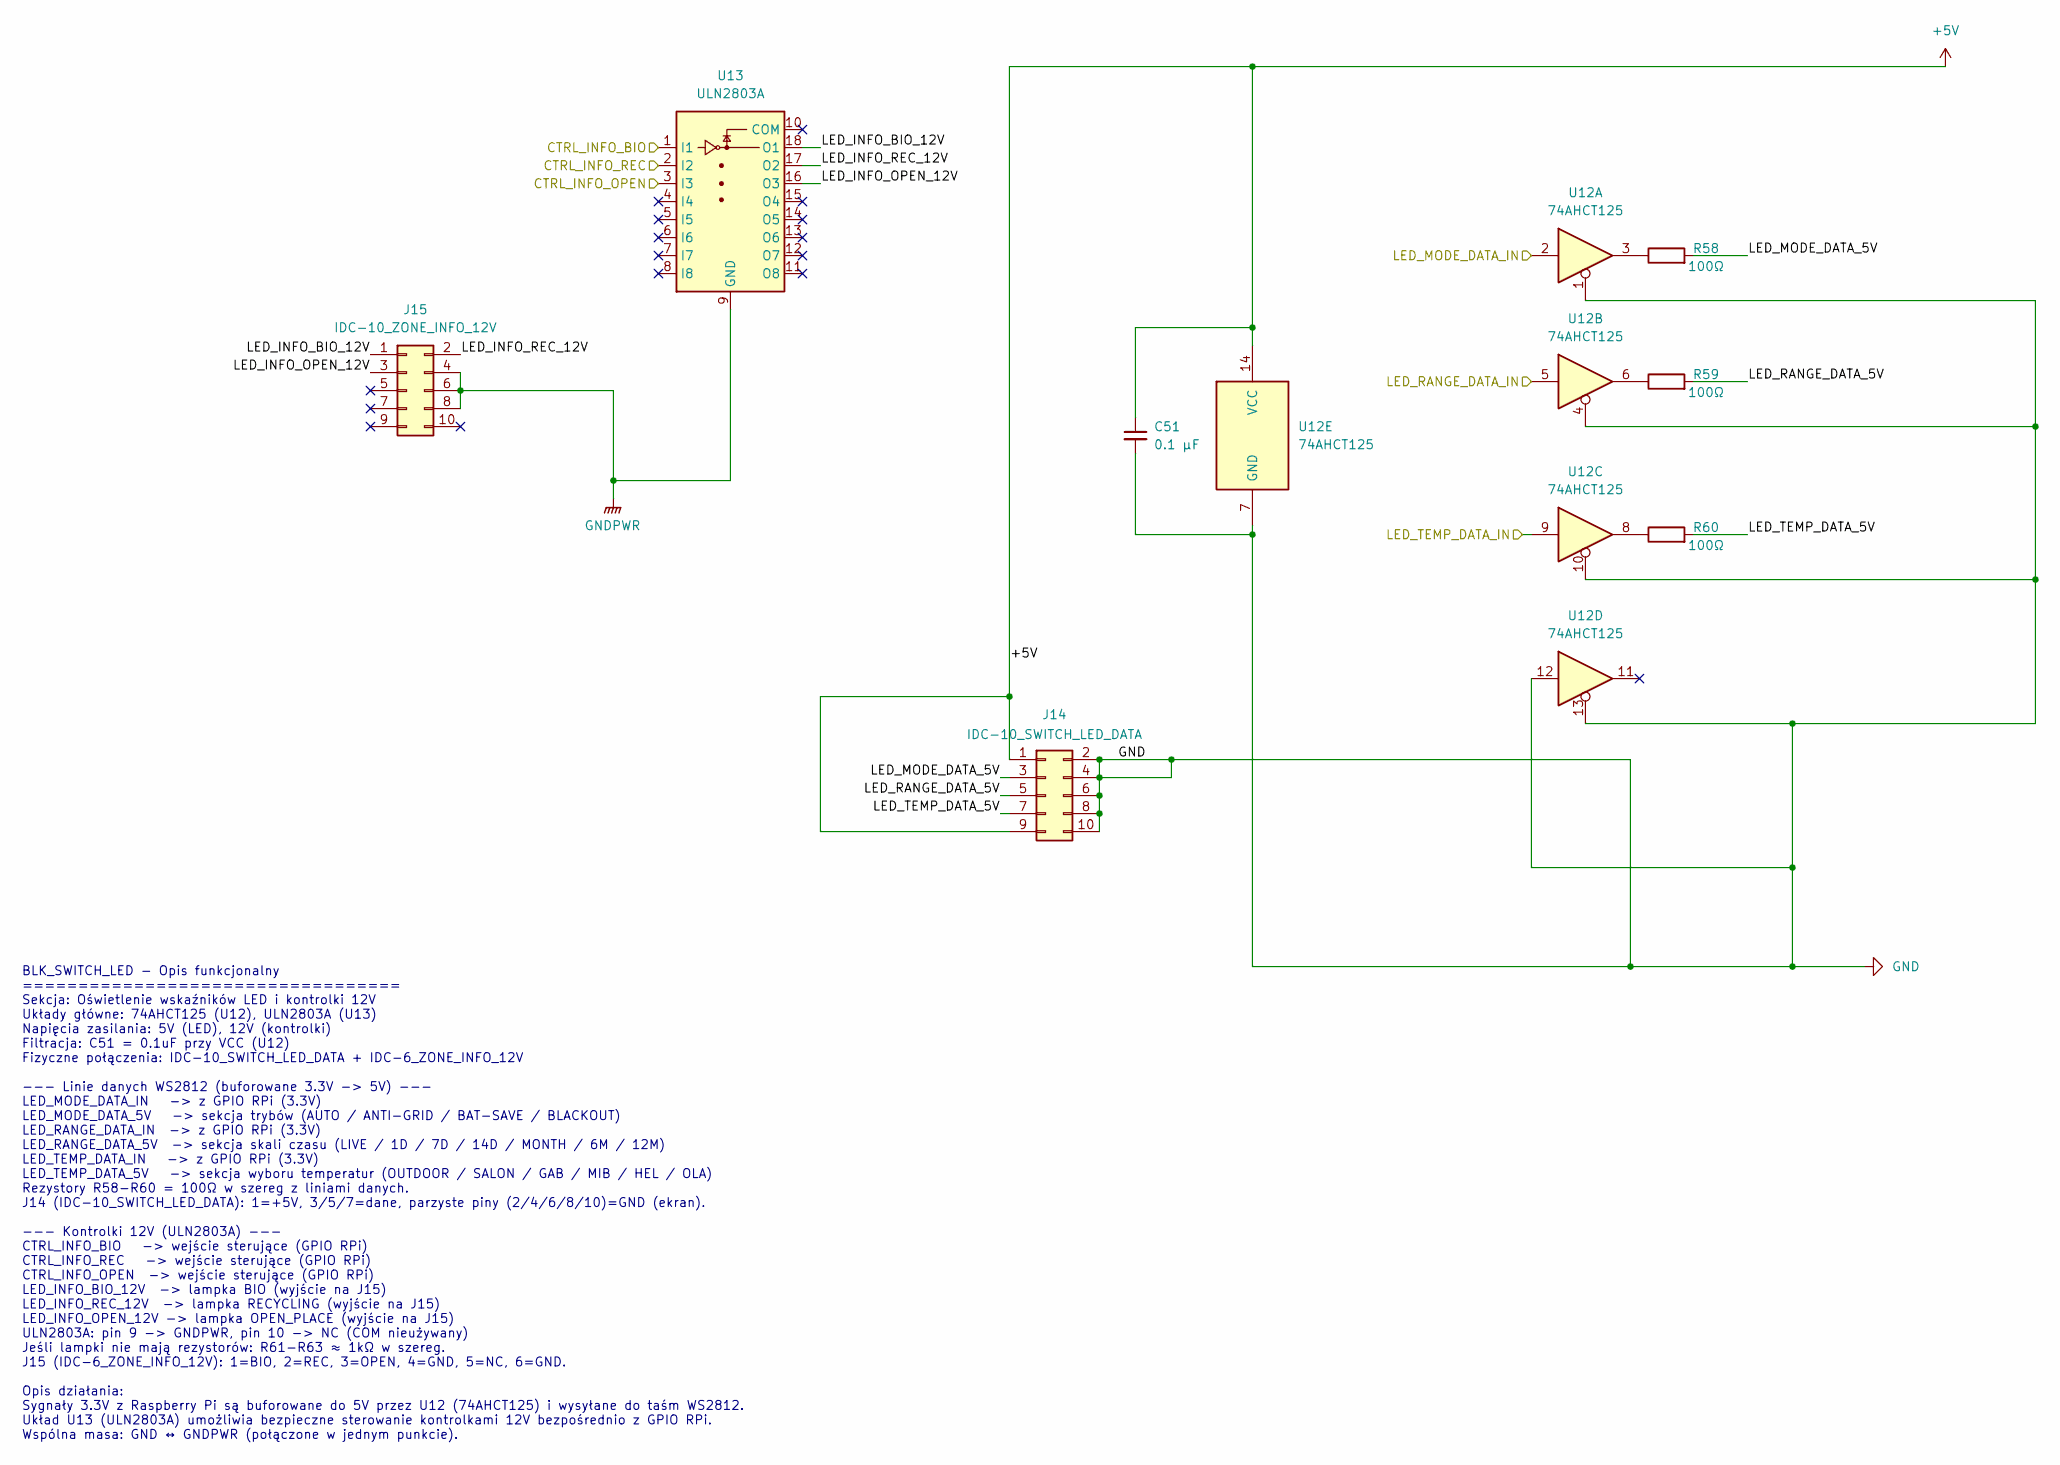
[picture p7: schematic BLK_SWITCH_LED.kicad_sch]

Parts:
C51: 0.1 µF; C_0603_1608Metric
J14: IDC-10_SWITCH_LED_DATA; IDC-Header_2x05_P2.54mm_Vertical
J15: IDC-10_ZONE_INFO_12V; IDC-Header_2x05_P2.54mm_Vertical
R58, R59, R60: 100Ω; R_0603_1608Metric
U12: 74AHCT125; SOIC-14_3.9x8.7mm_P1.27mm
U13: ULN2803A; SSOP-18_4.4x6.5mm_P0.65mm

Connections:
+5V: C51.1, J14.1, J14.9, U12.14 (VCC); also elsewhere on the board
/BLK_SWITCH_LED/LED_INFO_BIO_12V: J15.1, U13.18 (O1)
/BLK_SWITCH_LED/LED_INFO_OPEN_12V: J15.3, U13.16 (O3)
/BLK_SWITCH_LED/LED_INFO_REC_12V: J15.2, U13.17 (O2)
/BLK_SWITCH_LED/LED_MODE_DATA_5V: J14.3, R58.2
/BLK_SWITCH_LED/LED_MODE_DATA_IN: U12.2; also elsewhere on the board
/BLK_SWITCH_LED/LED_RANGE_DATA_5V: J14.5, R59.2
/BLK_SWITCH_LED/LED_RANGE_DATA_IN: U12.5; also elsewhere on the board
/BLK_SWITCH_LED/LED_TEMP_DATA_5V: J14.7, R60.2
/BLK_SWITCH_LED/LED_TEMP_DATA_IN: U12.9; also elsewhere on the board
/CTRL_INFO_BIO: U13.1 (I1); also elsewhere on the board
/CTRL_INFO_OPEN: U13.3 (I3); also elsewhere on the board
/CTRL_INFO_REC: U13.2 (I2); also elsewhere on the board
GND: C51.2, J14.2, J14.4, J14.6, J14.8, J14.10, U12.1, U12.4, U12.7 (GND), U12.10, U12.12, U12.13; also elsewhere on the board
GNDPWR: J15.4, J15.6, J15.8, U13.9 (GND); also elsewhere on the board
unnamed: R58.1, U12.3
unnamed: R59.1, U12.6
unnamed: R60.1, U12.8

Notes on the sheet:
BLK_SWITCH_LED - Opis funkcjonalny ================================== Sekcja: Oświetlenie wskaźników LED i kontrolki 12V Układy główne: 74AHCT125 (U12), ULN2803A (U13) Napięcia zasilania: 5V (LED), 12V (kontrolki) Filtracja: C51 = 0.1uF przy VCC (U12) Fizyczne połączenia: IDC-10_SWITCH_LED_DATA + I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

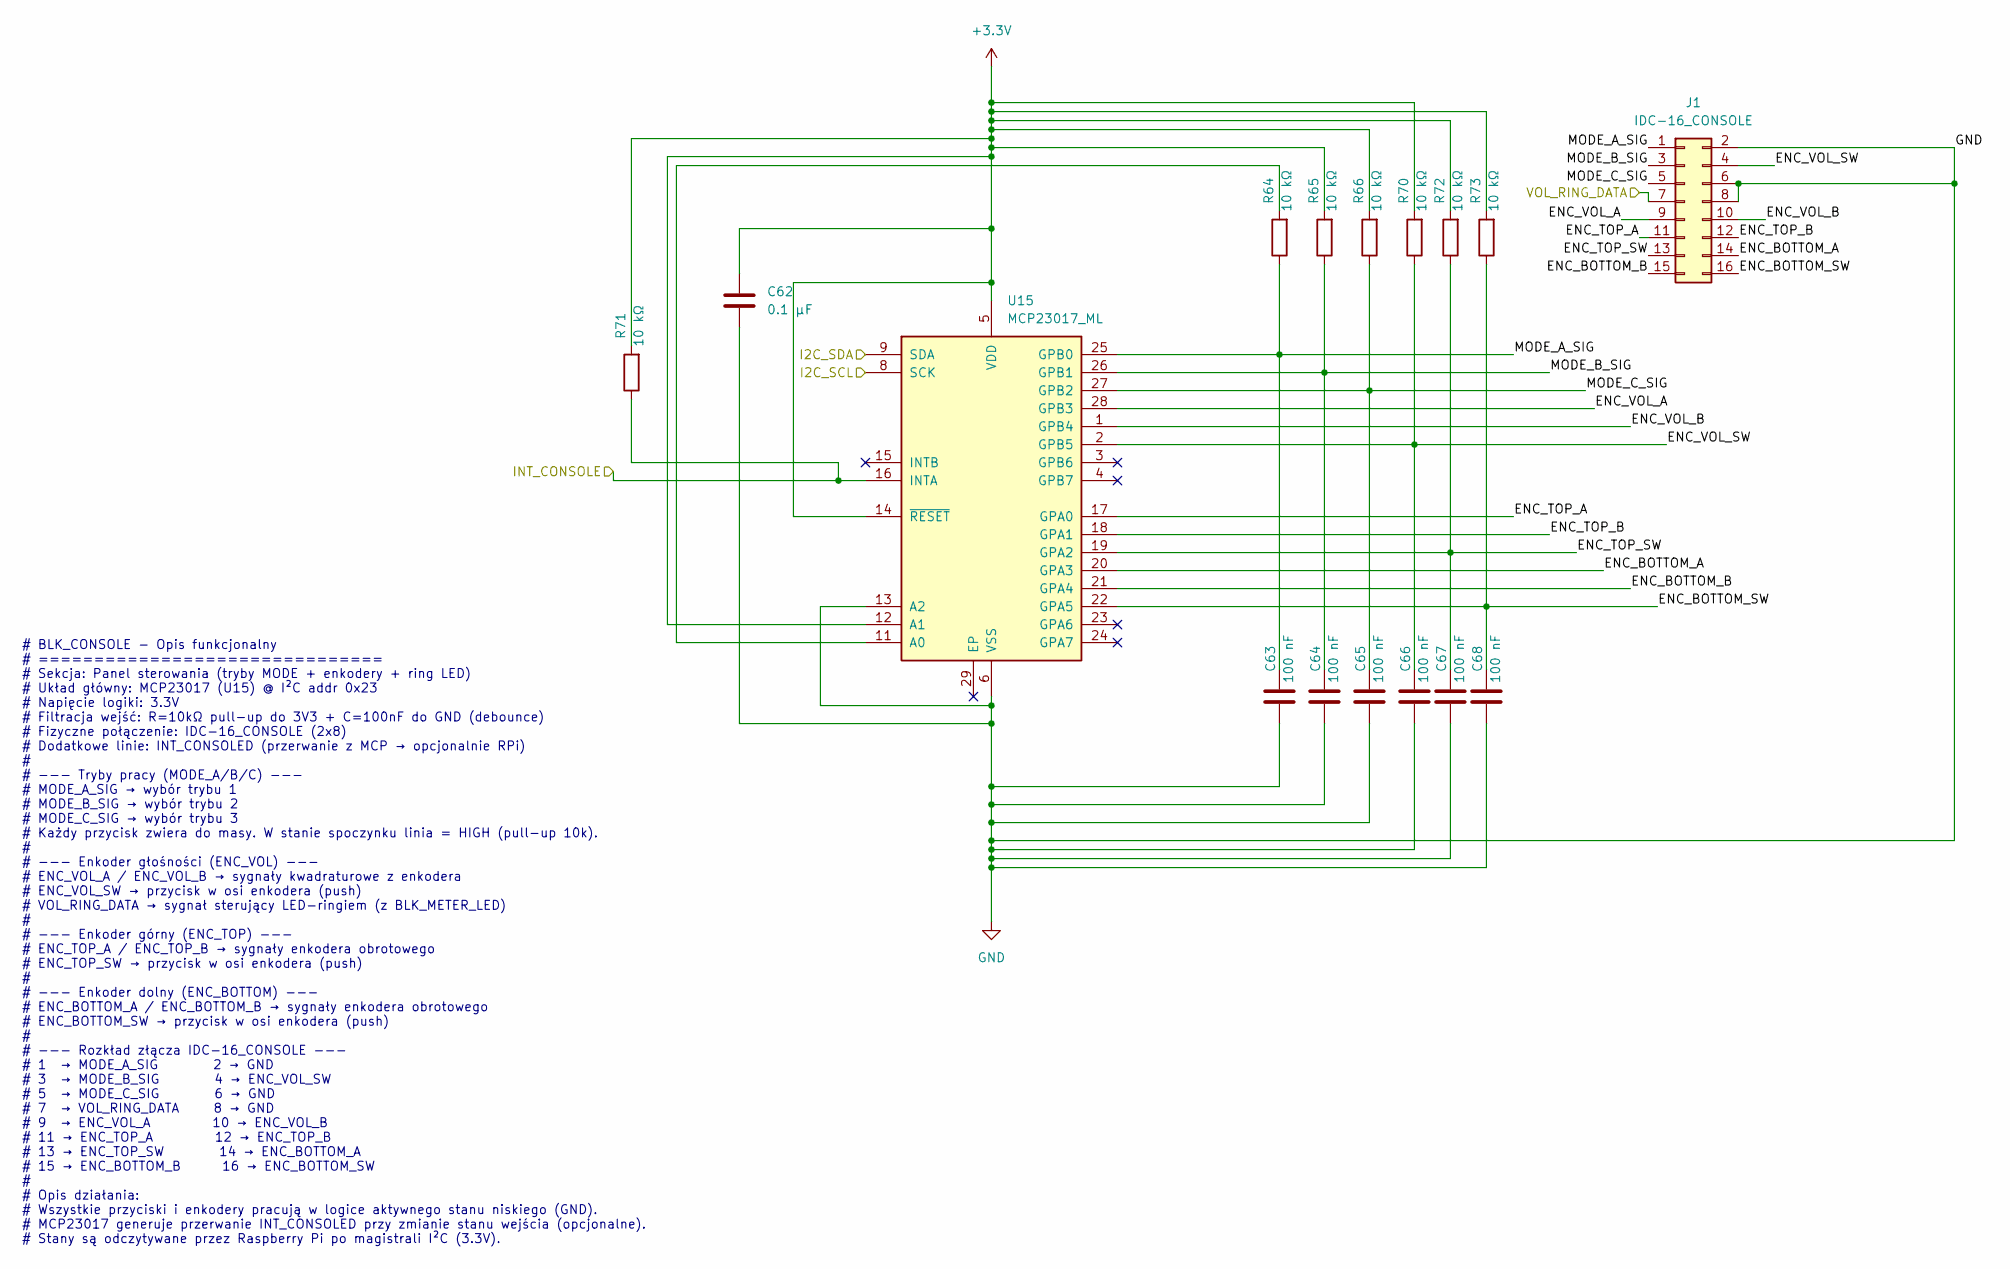
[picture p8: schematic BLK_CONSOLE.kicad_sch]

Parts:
C62: 0.1 µF; C_1206_3216Metric_Pad1.33x1.80mm_HandSolder
C63, C64, C65, C66, C67, C68: 100 nF; C_1206_3216Metric_Pad1.33x1.80mm_HandSolder
J1: IDC-16_CONSOLE; IDC-Header_2x08_P2.54mm_Vertical
R64, R65, R66, R70, R71, R72, R73: 10 kΩ; R_1206_3216Metric_Pad1.30x1.75mm_HandSolder
U15: MCP23017_ML; QFN-28-1EP_6x6mm_P0.65mm_EP4.25x4.25mm

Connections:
+3.3V: C62.2, R65.2, R66.2, R70.2, R71.2, R72.2, R73.2, U15.5 (VDD), U15.12 (A1), U15.14 (~RESET); also elsewhere on the board
/AUX_SCL: U15.8 (SCK); also elsewhere on the board
/AUX_SDA: U15.9 (SDA); also elsewhere on the board
/BLK_CONSOLE/ENC_BOTTOM_A: J1.14, U15.20 (GPA3)
/BLK_CONSOLE/ENC_BOTTOM_B: J1.15, U15.21 (GPA4)
/BLK_CONSOLE/ENC_BOTTOM_SW: C68.2, J1.16, R73.1, U15.22 (GPA5)
/BLK_CONSOLE/ENC_TOP_A: J1.11, U15.17 (GPA0)
/BLK_CONSOLE/ENC_TOP_B: J1.12, U15.18 (GPA1)
/BLK_CONSOLE/ENC_TOP_SW: C67.2, J1.13, R72.1, U15.19 (GPA2)
/BLK_CONSOLE/ENC_VOL_A: J1.9, U15.28 (GPB3)
/BLK_CONSOLE/ENC_VOL_B: J1.10, U15.1 (GPB4)
/BLK_CONSOLE/ENC_VOL_SW: C66.2, J1.4, R70.1, U15.2 (GPB5)
/BLK_CONSOLE/INT_CONSOLE: R71.1, U15.16 (INTA); also elsewhere on the board
/BLK_CONSOLE/MODE_A_SIG: C63.2, J1.1, R64.1, U15.25 (GPB0)
/BLK_CONSOLE/MODE_B_SIG: C64.2, J1.3, R65.1, U15.26 (GPB1)
/BLK_CONSOLE/MODE_C_SIG: C65.2, J1.5, R66.1, U15.27 (GPB2)
/BLK_CONSOLE/VOL_RING_DATA: J1.7; also elsewhere on the board
GND: C62.1, C63.1, C64.1, C65.1, C66.1, C67.1, C68.1, J1.2, J1.6, J1.8, U15.6 (VSS), U15.13 (A2); also elsewhere on the board
unnamed: R64.2, U15.11 (A0)

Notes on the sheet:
# BLK_CONSOLE - Opis funkcjonalny # =============================== # Sekcja: Panel sterowania (tryby MODE + enkodery + ring LED) # Układ główny: MCP23017 (U15) @ I²C addr 0x23 # Napięcie logiki: 3.3V # Filtracja wejść: R=10kΩ pull-up do 3V3 + C=100nF do GND (debounce) # Fizyczne połączenie: IDC-16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

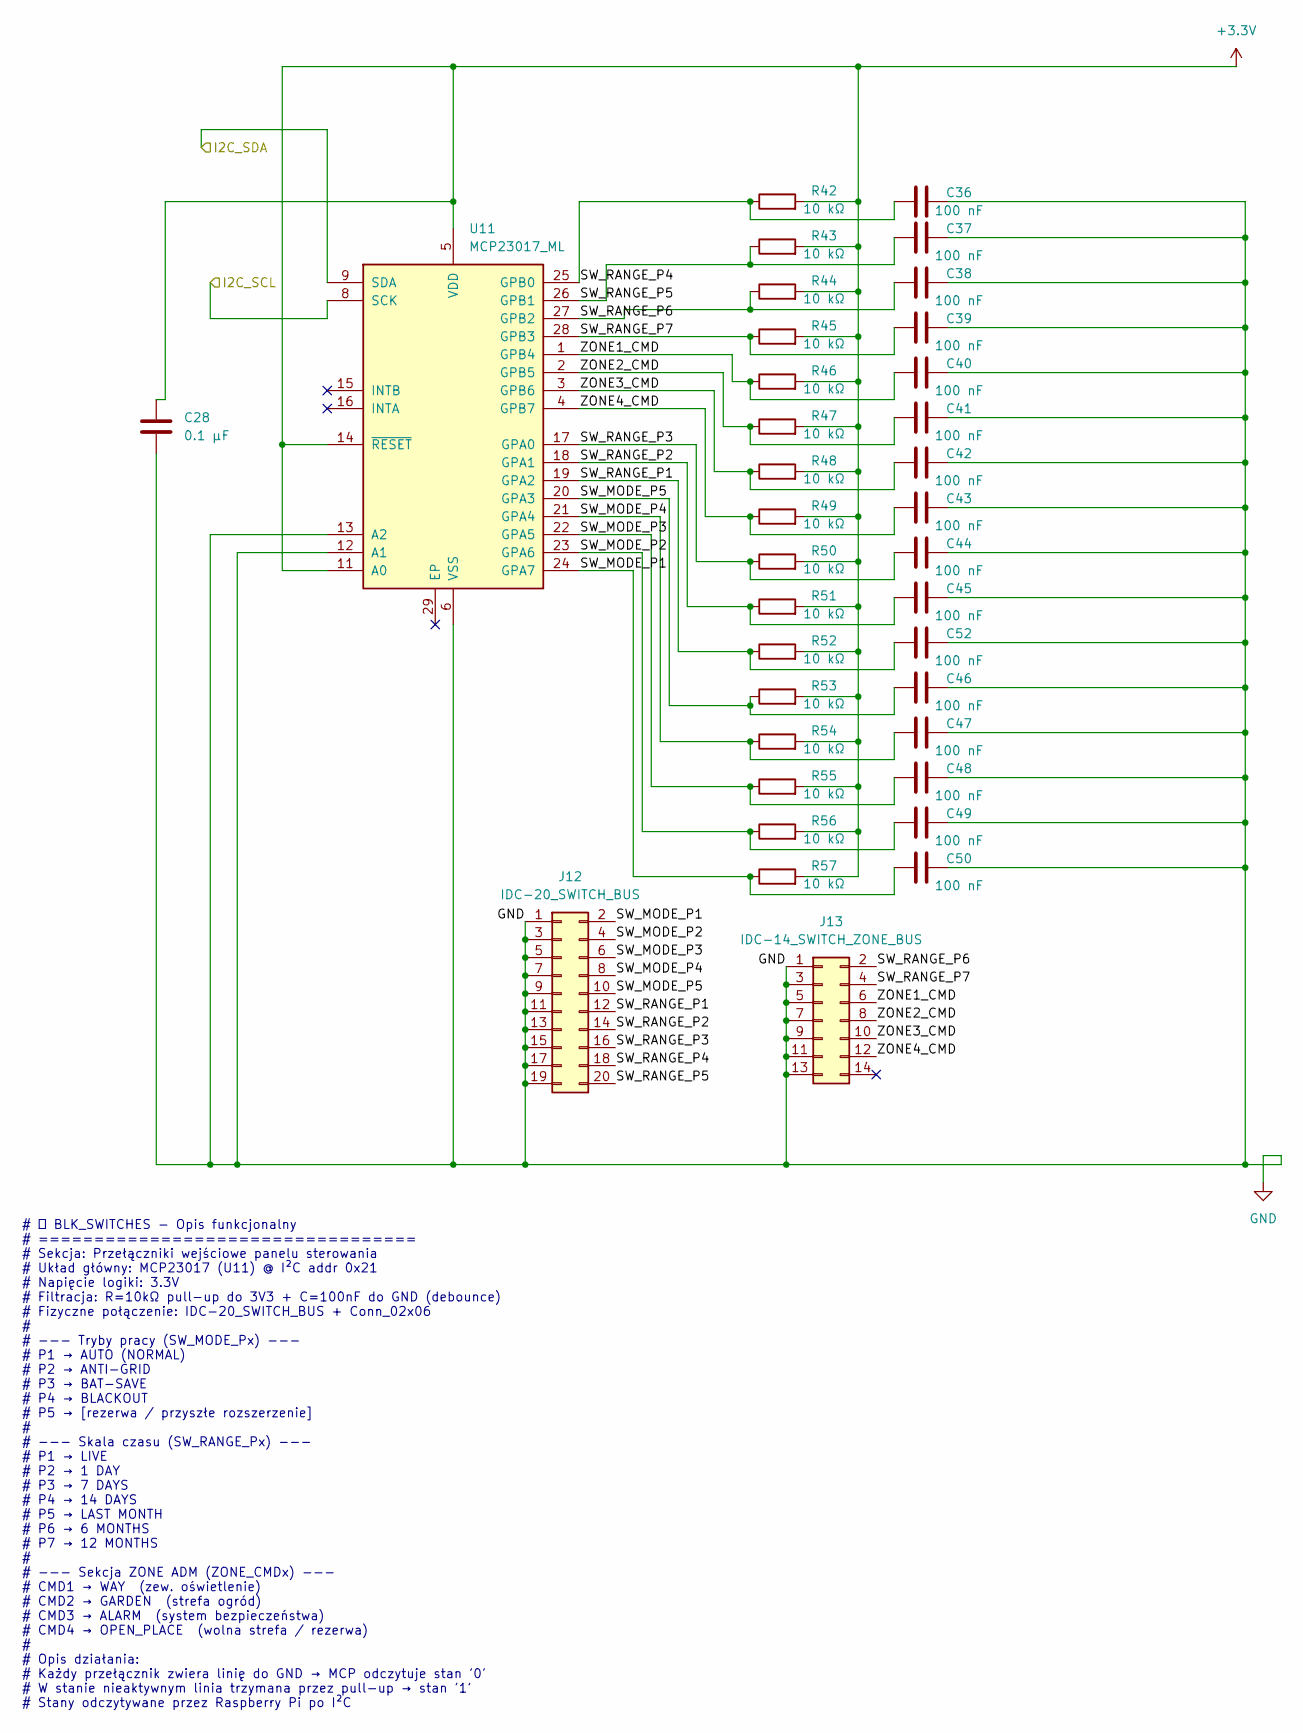
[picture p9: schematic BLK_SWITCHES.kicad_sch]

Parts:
C28: 0.1 µF; C_1206_3216Metric_Pad1.33x1.80mm_HandSolder
C36, C37, C38, C39, C40, C41, C42, C43, C44, C45, C46, C47, C48, C49, C50, C52: 100 nF; C_1206_3216Metric_Pad1.33x1.80mm_HandSolder
J12: IDC-20_SWITCH_BUS; IDC-Header_2x10_P2.54mm_Vertical
J13: IDC-14_SWITCH_ZONE_BUS; IDC-Header_2x07_P2.54mm_Vertical
R42, R43, R44, R45, R46, R47, R48, R49, R50, R51, R52, R53, R54, R55, R56, R57: 10 kΩ; R_1206_3216Metric_Pad1.30x1.75mm_HandSolder
U11: MCP23017_ML; QFN-28-1EP_6x6mm_P0.65mm_EP4.25x4.25mm

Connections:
+3.3V: C28.2, R42.2, R43.2, R44.2, R45.2, R46.2, R47.2, R48.2, R49.2, R50.2, R51.2, R52.2, R53.2, R54.2, R55.2, R56.2, R57.2, U11.5 (VDD), U11.11 (A0), U11.14 (~RESET); also elsewhere on the board
/AUX_SCL: U11.8 (SCK); also elsewhere on the board
/AUX_SDA: U11.9 (SDA); also elsewhere on the board
/BLK_SWITCHES/SW_MODE_P1: C50.1, J12.2, R57.1, U11.24 (GPA7)
/BLK_SWITCHES/SW_MODE_P2: C49.1, J12.4, R56.1, U11.23 (GPA6)
/BLK_SWITCHES/SW_MODE_P3: C48.1, J12.6, R55.1, U11.22 (GPA5)
/BLK_SWITCHES/SW_MODE_P4: C47.1, J12.8, R54.1, U11.21 (GPA4)
/BLK_SWITCHES/SW_MODE_P5: C46.1, J12.10, R53.1, U11.20 (GPA3)
/BLK_SWITCHES/SW_RANGE_P1: C52.1, J12.12, R52.1, U11.19 (GPA2)
/BLK_SWITCHES/SW_RANGE_P2: C45.1, J12.14, R51.1, U11.18 (GPA1)
/BLK_SWITCHES/SW_RANGE_P3: C44.1, J12.16, R50.1, U11.17 (GPA0)
/BLK_SWITCHES/SW_RANGE_P4: C36.1, J12.18, R42.1, U11.25 (GPB0)
/BLK_SWITCHES/SW_RANGE_P5: C37.1, J12.20, R43.1, U11.26 (GPB1)
/BLK_SWITCHES/SW_RANGE_P6: C38.1, J13.2, R44.1, U11.27 (GPB2)
/BLK_SWITCHES/SW_RANGE_P7: C39.1, J13.4, R45.1, U11.28 (GPB3)
/BLK_SWITCHES/ZONE1_CMD: C40.1, J13.6, R46.1, U11.1 (GPB4)
/BLK_SWITCHES/ZONE2_CMD: C41.1, J13.8, R47.1, U11.2 (GPB5)
/BLK_SWITCHES/ZONE3_CMD: C42.1, J13.10, R48.1, U11.3 (GPB6)
/BLK_SWITCHES/ZONE4_CMD: C43.1, J13.12, R49.1, U11.4 (GPB7)
GND: C28.1, C36.2, C37.2, C38.2, C39.2, C40.2, C41.2, C42.2, C43.2, C44.2, C45.2, C46.2, C47.2, C48.2, C49.2, C50.2, C52.2, J12.1, J12.3, J12.5, J12.7, J12.9, J12.11, J12.13, J12.15, J12.17, J12.19, J13.1, J13.3, J13.5, J13.7, J13.9, J13.11, J13.13, U11.6 (VSS), U11.12 (A1), U11.13 (A2); also elsewhere on the board

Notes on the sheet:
# 🟡 BLK_SWITCHES - Opis funkcjonalny # ================================== # Sekcja: Przełączniki wejściowe panelu sterowania # Układ główny: MCP23017 (U11) @ I²C addr 0x21 # Napięcie logiki: 3.3V # Filtracja: R=10kΩ pull-up do 3V3 + C=100nF do GND (debounce) # Fizyczne połączenie: IDC-20_SWITCH_BUS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

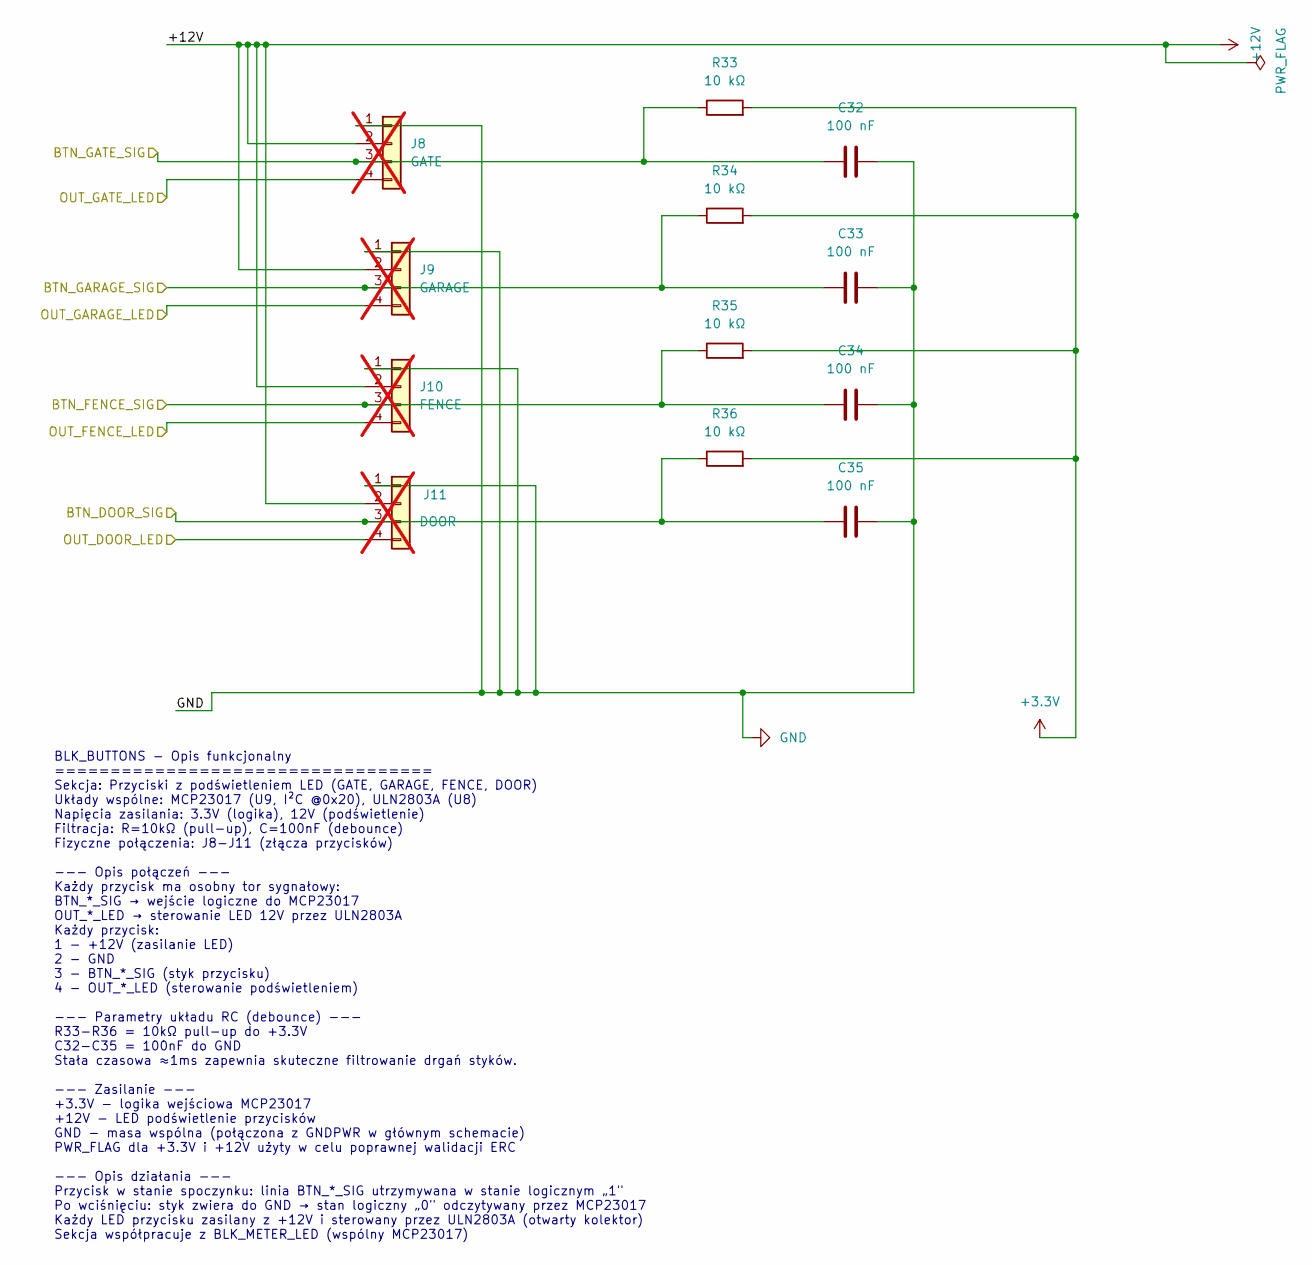
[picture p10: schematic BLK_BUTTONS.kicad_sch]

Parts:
C32, C33, C34, C35: 100 nF; C_1206_3216Metric_Pad1.33x1.80mm_HandSolder
J8: GATE; not fitted
J9: GARAGE; not fitted
J10: FENCE; not fitted
J11: DOOR; not fitted
R33, R34, R35, R36: 10 kΩ; R_1206_3216Metric_Pad1.30x1.75mm_HandSolder

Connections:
+3.3V: R33.2, R34.2, R35.2, R36.2; also elsewhere on the board
/BLK_BUTTONS/BTN_DOOR_SIG: C35.1, J11.3, R36.1; also elsewhere on the board
/BLK_BUTTONS/BTN_FENCE_SIG: C34.2, J10.3, R35.1; also elsewhere on the board
/BLK_BUTTONS/BTN_GARAGE_SIG: C33.2, J9.3, R34.1; also elsewhere on the board
/BLK_BUTTONS/BTN_GATE_SIG: C32.2, J8.3, R33.1; also elsewhere on the board
GND: C32.1, C33.1, C34.1, C35.2, J8.1, J9.1, J10.1, J11.1; also elsewhere on the board
unnamed: J8.2, J9.2, J10.2, J11.2

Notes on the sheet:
BLK_BUTTONS - Opis funkcjonalny ================================== Sekcja: Przyciski z podświetleniem LED (GATE, GARAGE, FENCE, DOOR) Układy wspólne: MCP23017 (U9, I²C @0x20), ULN2803A (U8) Napięcia zasilania: 3.3V (logika), 12V (podświetlenie) Filtracja: R=10kΩ (pull-up), C=100nF (debounce) Fizycz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

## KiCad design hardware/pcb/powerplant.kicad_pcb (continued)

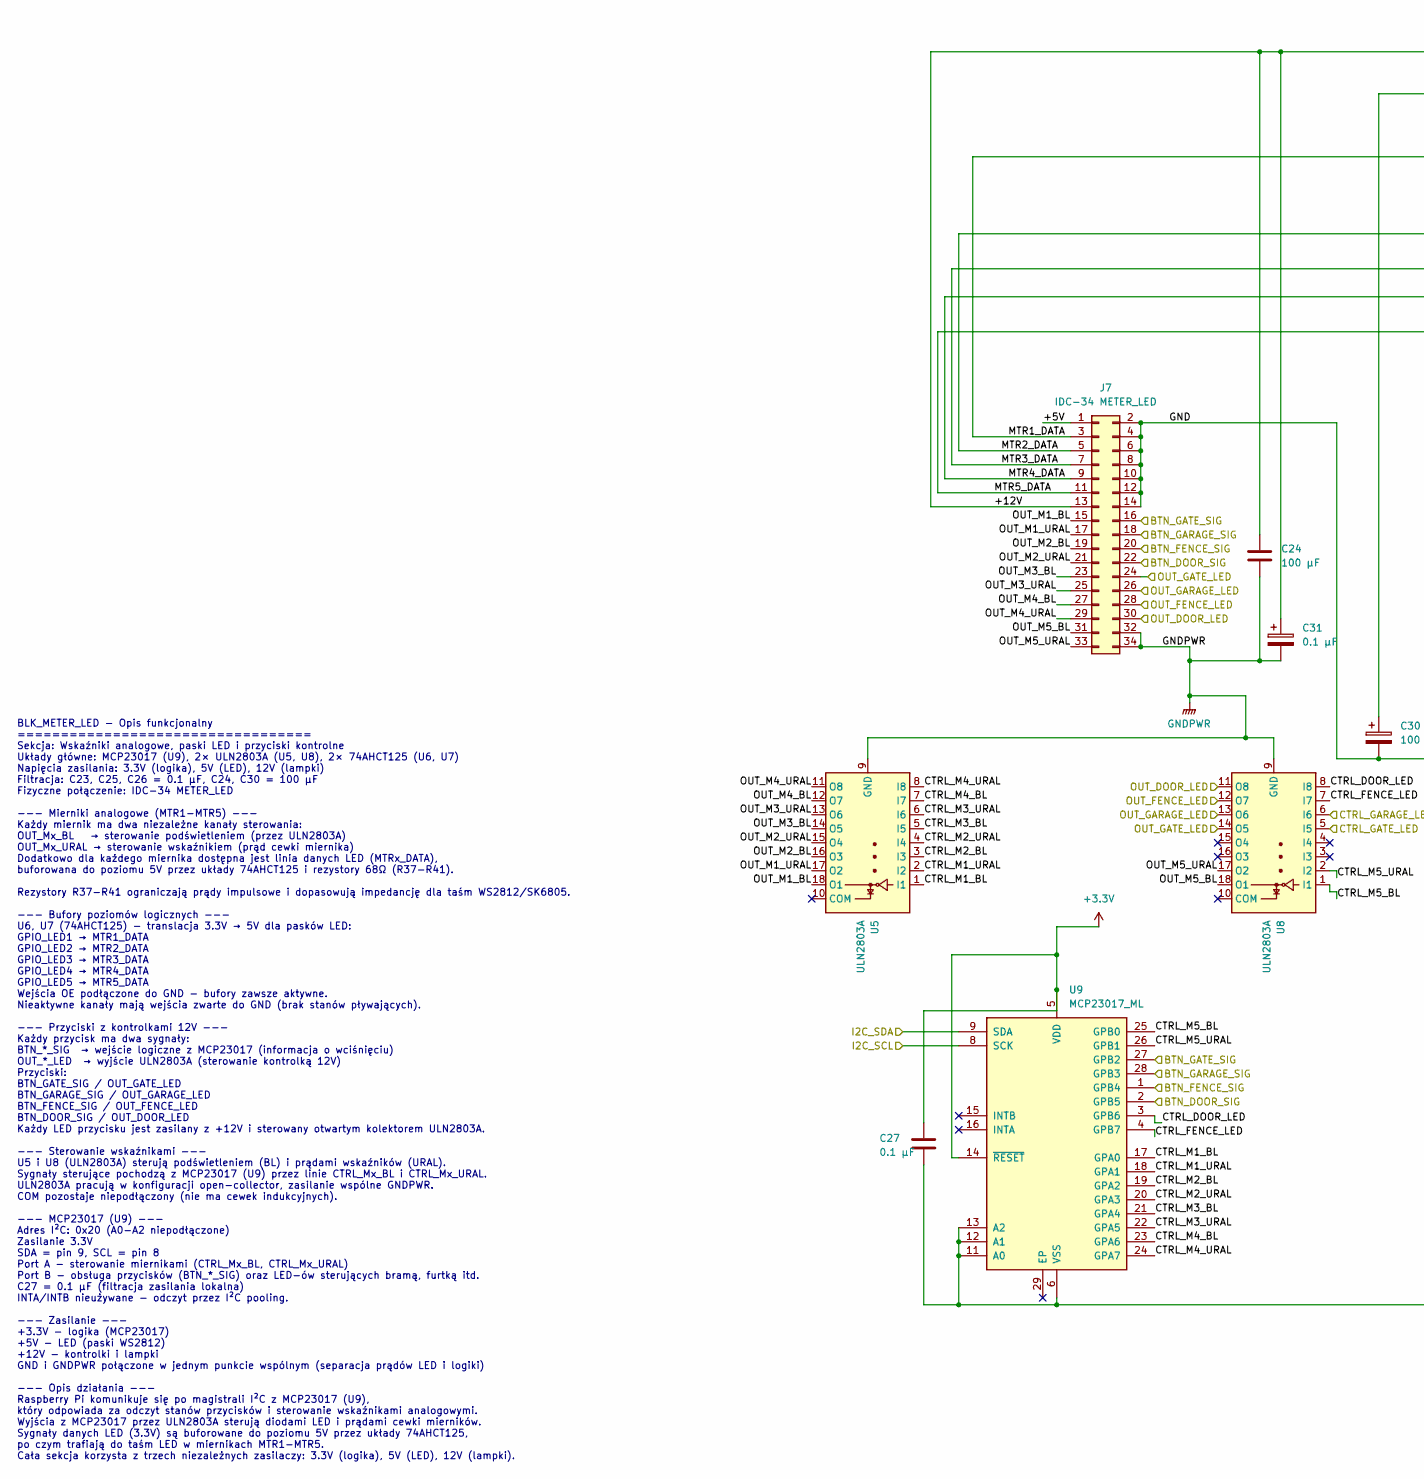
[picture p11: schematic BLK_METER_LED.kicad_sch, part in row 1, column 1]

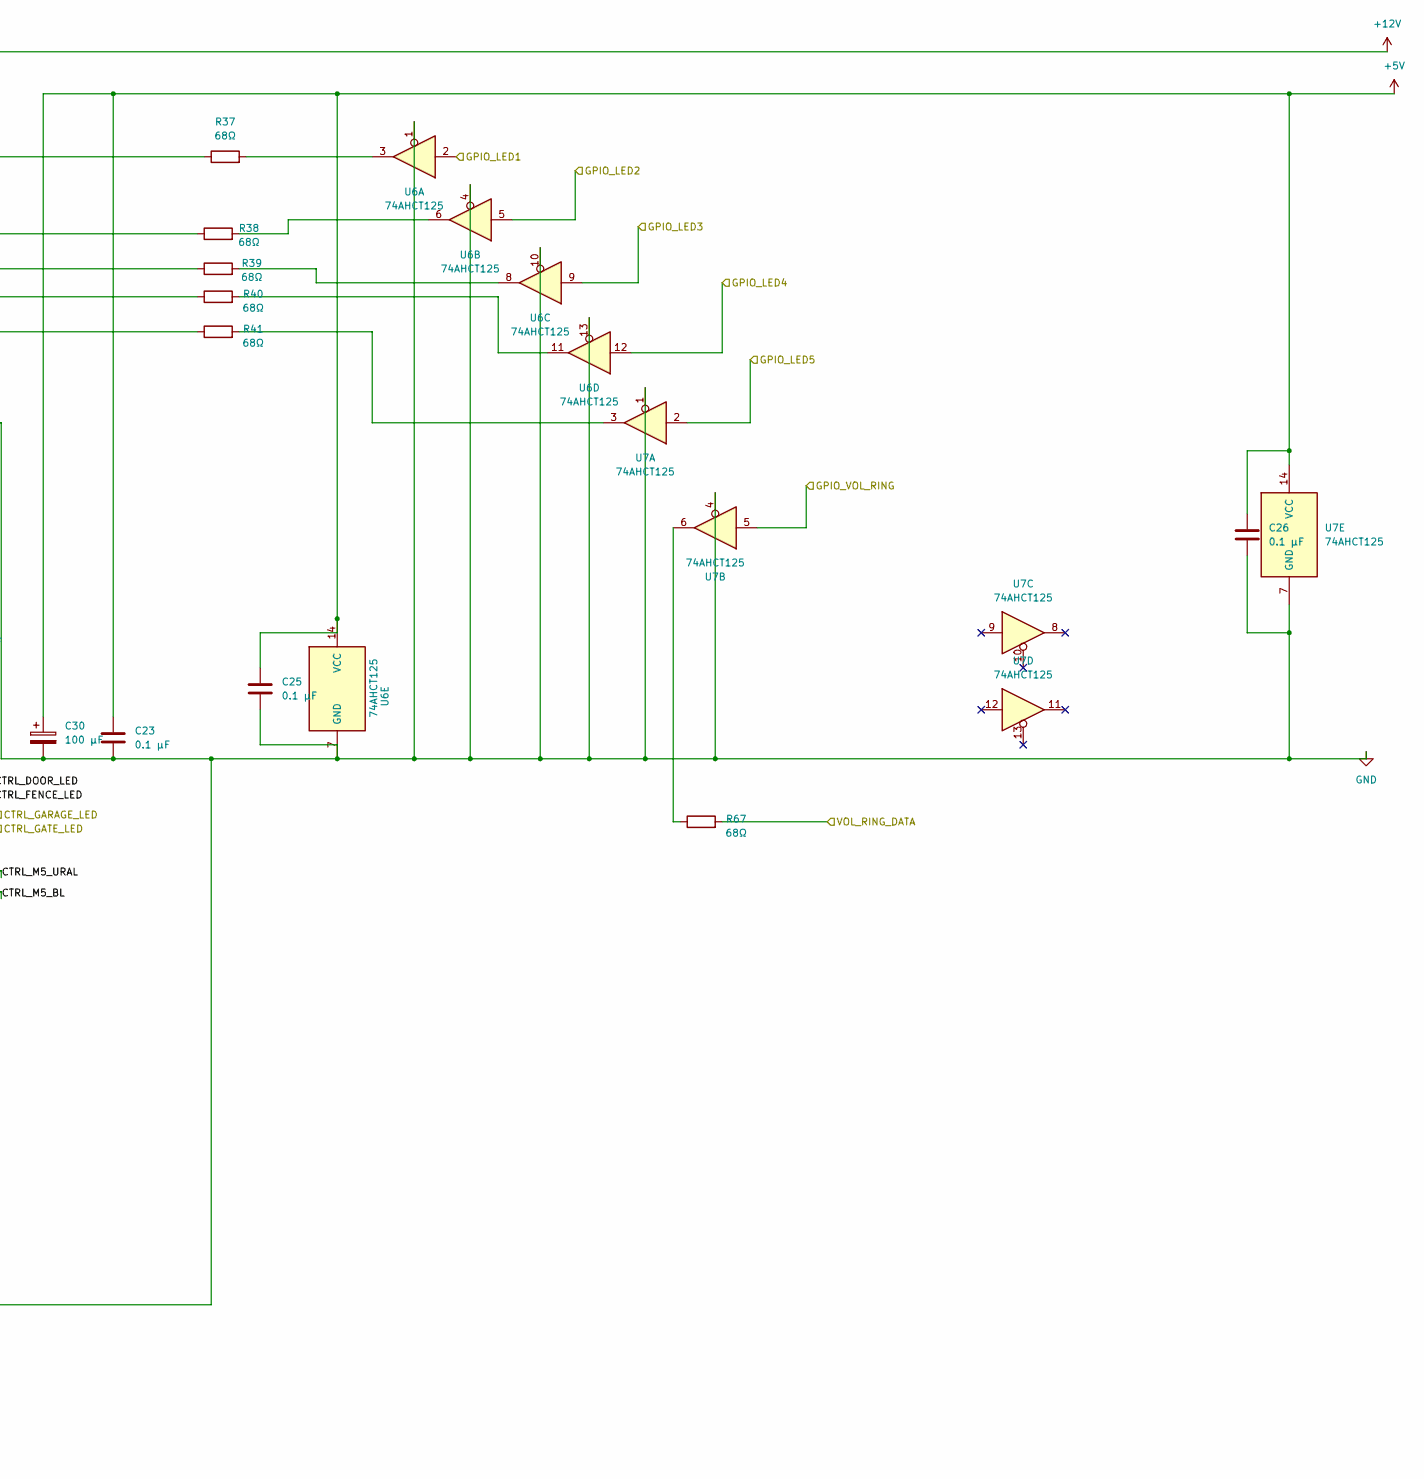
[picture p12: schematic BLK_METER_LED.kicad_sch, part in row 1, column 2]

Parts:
C23, C25, C26, C27: 0.1 µF; C_1206_3216Metric_Pad1.33x1.80mm_HandSolder
C24, C30: 100 µF; CP_Radial_D5.0mm_P2.50mm
C31: 0.1 µF; C_1206_3216Metric
J7: IDC-34 METER_LED; IDC-Header_2x17_P2.54mm_Vertical
R37, R38, R39, R40, R41, R67: 68Ω; R_1206_3216Metric_Pad1.30x1.75mm_HandSolder
U5, U8: ULN2803A; SOIC-18W_7.5x11.6mm_P1.27mm
U6, U7: 74AHCT125; SOIC-14_3.9x8.7mm_P1.27mm
U9: MCP23017_ML; QFN-28-1EP_6x6mm_P0.65mm_EP4.25x4.25mm

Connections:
+3.3V: C27.2, U9.5 (VDD), U9.14 (~RESET); also elsewhere on the board
+5V: C23.2, C25.2, C26.2, C30.1, J7.1, U6.14 (VCC), U7.14 (VCC); also elsewhere on the board
+12V: C24.2, C31.1, J7.13; also elsewhere on the board
/AUX_SCL: U9.8 (SCK); also elsewhere on the board
/AUX_SDA: U9.9 (SDA); also elsewhere on the board
/BLK_BUTTONS/BTN_DOOR_SIG: J7.22, U9.2 (GPB5); also elsewhere on the board
/BLK_BUTTONS/BTN_FENCE_SIG: J7.20, U9.1 (GPB4); also elsewhere on the board
/BLK_BUTTONS/BTN_GARAGE_SIG: J7.18, U9.28 (GPB3); also elsewhere on the board
/BLK_BUTTONS/BTN_GATE_SIG: J7.16, U9.27 (GPB2); also elsewhere on the board
/BLK_BUTTONS/OUT_DOOR_LED: J7.30, U8.11 (O8)
/BLK_BUTTONS/OUT_FENCE_LED: J7.28, U8.12 (O7)
/BLK_BUTTONS/OUT_GARAGE_LED: J7.26, U8.13 (O6)
/BLK_BUTTONS/OUT_GATE_LED: J7.24, U8.14 (O5)
/BLK_CONSOLE/VOL_RING_DATA: R67.2; also elsewhere on the board
/BLK_METER_LED/CTRL_DOOR_LED: U8.8 (I8), U9.3 (GPB6)
/BLK_METER_LED/CTRL_FENCE_LED: U8.7 (I7), U9.4 (GPB7)
/BLK_METER_LED/CTRL_GARAGE_LED: U8.6 (I6); also elsewhere on the board
/BLK_METER_LED/CTRL_GATE_LED: U8.5 (I5); also elsewhere on the board
/BLK_METER_LED/CTRL_M1_BL: U5.1 (I1), U9.17 (GPA0)
/BLK_METER_LED/CTRL_M1_URAL: U5.2 (I2), U9.18 (GPA1)
/BLK_METER_LED/CTRL_M2_BL: U5.3 (I3), U9.19 (GPA2)
/BLK_METER_LED/CTRL_M2_URAL: U5.4 (I4), U9.20 (GPA3)
/BLK_METER_LED/CTRL_M3_BL: U5.5 (I5), U9.21 (GPA4)
/BLK_METER_LED/CTRL_M3_URAL: U5.6 (I6), U9.22 (GPA5)
/BLK_METER_LED/CTRL_M4_BL: U5.7 (I7), U9.23 (GPA6)
/BLK_METER_LED/CTRL_M4_URAL: U5.8 (I8), U9.24 (GPA7)
/BLK_METER_LED/CTRL_M5_BL: U8.1 (I1), U9.25 (GPB0)
/BLK_METER_LED/CTRL_M5_URAL: U8.2 (I2), U9.26 (GPB1)
/BLK_METER_LED/GPIO_LED1: U6.2; also elsewhere on the board
/BLK_METER_LED/GPIO_LED2: U6.5; also elsewhere on the board
/BLK_METER_LED/GPIO_LED3: U6.9; also elsewhere on the board
/BLK_METER_LED/GPIO_LED4: U6.12; also elsewhere on the board
/BLK_METER_LED/GPIO_LED5: U7.2; also elsewhere on the board
/BLK_METER_LED/GPIO_VOL_RING: U7.5; also elsewhere on the board
/BLK_METER_LED/MTR1_DATA: J7.3, R37.1
/BLK_METER_LED/MTR2_DATA: J7.5, R38.1
/BLK_METER_LED/MTR3_DATA: J7.7, R39.1
/BLK_METER_LED/MTR4_DATA: J7.9, R40.1
/BLK_METER_LED/MTR5_DATA: J7.11, R41.1
/BLK_METER_LED/OUT_M1_BL: J7.15, U5.18 (O1)
/BLK_METER_LED/OUT_M1_URAL: J7.17, U5.17 (O2)
/BLK_METER_LED/OUT_M2_BL: J7.19, U5.16 (O3)
/BLK_METER_LED/OUT_M2_URAL: J7.21, U5.15 (O4)
/BLK_METER_LED/OUT_M3_BL: J7.23, U5.14 (O5)
/BLK_METER_LED/OUT_M3_URAL: J7.25, U5.13 (O6)
/BLK_METER_LED/OUT_M4_BL: J7.27, U5.12 (O7)
/BLK_METER_LED/OUT_M4_URAL: J7.29, U5.11 (O8)
/BLK_METER_LED/OUT_M5_BL: J7.31, U8.18 (O1)
/BLK_METER_LED/OUT_M5_URAL: J7.33, U8.17 (O2)
GND: C23.1, C25.1, C26.1, C27.1, C30.2, J7.2, J7.4, J7.6, J7.8, J7.10, J7.12, J7.14, U6.1, U6.4, U6.7 (GND), U6.10, U6.13, U7.1, U7.4, U7.7 (GND), U9.6 (VSS), U9.11 (A0), U9.12 (A1), U9.13 (A2); also elsewhere on the board
GNDPWR: C24.1, C31.2, J7.32, J7.34, U5.9 (GND), U8.9 (GND); also elsewhere on the board
unnamed: R37.2, U6.3
unnamed: R38.2, U6.6
unnamed: R39.2, U6.8
unnamed: R40.2, U6.11
unnamed: R41.2, U7.3
unnamed: R67.1, U7.6

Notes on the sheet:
BLK_METER_LED - Opis funkcjonalny ================================== Sekcja: Wskaźniki analogowe, paski LED i przyciski kontrolne Układy główne: MCP23017 (U9), 2× ULN2803A (U5, U8), 2× 74AHCT125 (U6, U7) Napięcia zasilania: 3.3V (logika), 5V (LED), 12V (lampki) Filtracja: C23, C25, C26 = 0.1 µF, C2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

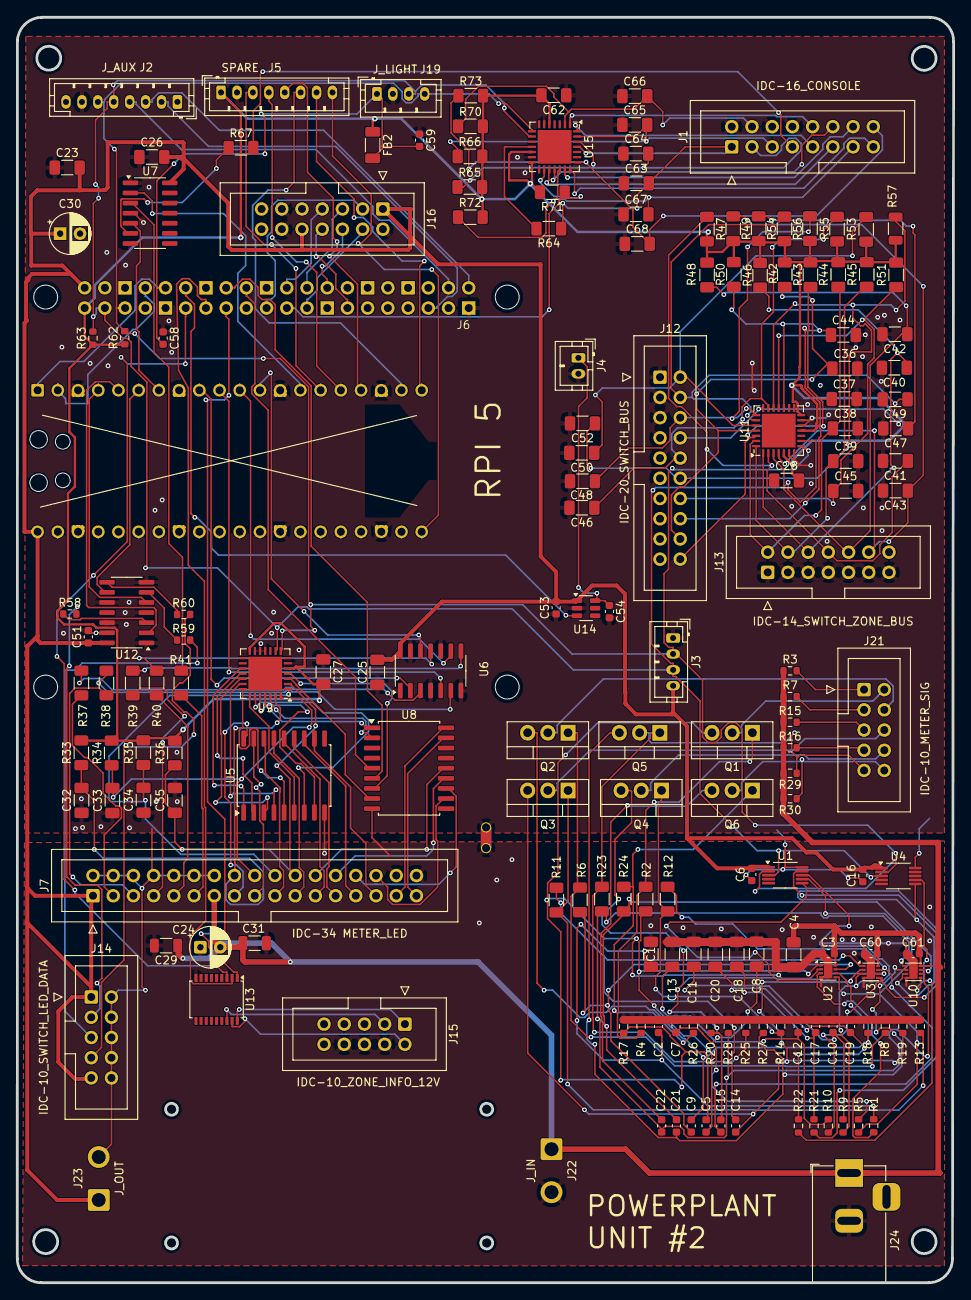
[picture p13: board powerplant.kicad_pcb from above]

Board: 2 copper layers, 117.6 x 159.0 mm, 174 parts (1 on the bottom side), 162 nets.

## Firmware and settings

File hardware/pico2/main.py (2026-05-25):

# Pico 2 – MTR1_DATA (34 LEDy) + podświetlenie 5 pasków WS2812 z RPi przez UART.
#
# Pico GPIO6 → MTR1_DATA (34 LEDy). Pico GPIO11..15 → dane WS2812: MTR1,MTR2 po 2 LED (kWh, Hz – pary 1-2 i 3-4 jako jedno), MTR3..5 po 40 LED.
#
# Protokół: 0xFF = ping | 0x01 + 102B = 34 LEDy | 0x02 + 1B maska + 3B R,G,B | 0x03 = backlight OFF | 0x04 OTA = 2B len + body → main.py, reboot.

from machine import UART, Pin, soft_reset
import neopixel
import time

UART_RX = 1
UART_TX = 0
MTR1_DATA_PIN = 6
BACKLIGHT_PINS = [11, 12, 13, 14, 15]   # MTR1..MTR5 (J5 spare)
# MTR1 (kWh), MTR2 (Hz) = po 2 LED, traktowane jako jedno przy podświetlaniu; MTR3..5 = po 40 LED
BACKLIGHT_LED_COUNTS = [2, 2, 40, 40, 40]
NUM_LEDS = 34
BAUD = 115200
# Strip MTR1_DATA (łuk): wiele taśm WS2812 ma kolejność GRB – wtedy (255,0,0) z hosta daje czerwony
# Ustaw False jeśli kolory się nie zgadzają (np. czerwony świeci na zielono).
MTR1_STRIP_GRB = True

CMD_PING = 0xFF
CMD_SET_STRIP = 0x01
CMD_BACKLIGHT_MASK = 0x02   # +1 B maska (bit0..4 = MTR1..5) + 3 B R,G,B – kolor z danych
CMD_BACKLIGHT_OFF = 0x03
CMD_OTA = 0x04   # + 2 B długość (big-endian) + body → zapis do main.py, soft_reset()
OTA_MAX_SIZE = 16384   # max 16 KB

def main():
    uart = UART(0, BAUD, tx=Pin(UART_TX), rx=Pin(UART_RX), timeout=0)
    np = neopixel.NeoPixel(Pin(MTR1_DATA_PIN), NUM_LEDS)
    bl_strips = [neopixel.NeoPixel(Pin(p), n) for p, n in zip(BACKLIGHT_PINS, BACKLIGHT_LED_COUNTS)]
    for bl, n in zip(bl_strips, BACKLIGHT_LED_COUNTS):
        for i in range(n):
            bl[i] = (0, 0, 0)
        bl.write()

    while True:
        buf = uart.read(1)
        if not buf:
            time.sleep_ms(10)
            continue

        cmd = buf[0]

        if cmd == CMD_PING:
            uart.write(bytes([CMD_PING]))
            continue

        if cmd == CMD_SET_STRIP:
            # Zbierz 102 B (34×RGB) – przy timeout=0 read() może zwrócić mniej
            need = NUM_LEDS * 3
            data = b""
            deadline = time.ticks_add(time.ticks_ms(), 200)
            while len(data) < need and time.ticks_diff(deadline, time.ticks_ms()) > 0:
                chunk = uart.read(need - len(data))
                if chunk:
                    data += chunk
                if len(data) < need:
                    time.sleep_ms(2)
            if len(data) >= need:
                for i in range(NUM_LEDS):
                    r = data[i * 3] & 0xFF
                    g = data[i * 3 + 1] & 0xFF
                    b = data[i * 3 + 2] & 0xFF
                    if MTR1_STRIP_GRB:
                        np[i] = (g, r, b)
                    else:
                        np[i] = (r, g, b)
                np.write()
            continue

        if cmd == CMD_BACKLIGHT_MASK:
            # Zbierz 4 B (maska + R,G,B) – przy timeout=0 read() może zwrócić mniej
            data = b""
            deadline = time.ticks_add(time.ticks_ms(), 100)
            while len(data) < 4 and time.ticks_diff(deadline, time.ticks_ms()) > 0:
                chunk = uart.read(4 - len(data))
                if chunk:
                    data += chunk
                if len(data) < 4:
                    time.sleep_ms(2)
            if len(data) >= 4:
                mask = data[0] & 0x1F
                r, g, b = data[1] & 0xFF, data[2] & 0xFF, data[3] & 0xFF
                # Taśma WS2812 w praktyce często GRB – podaj (G,R,B) żeby wyświetlić kolor (R,G,B)
                c = (g, r, b)
                for i in range(5):
                    color = c if (mask >> i) & 1 else (0, 0, 0)
                    n = BACKLIGHT_LED_COUNTS[i]
                    for j in range(n):
                        bl_strips[i][j] = color
                    bl_strips[i].write()
            continue

        if cmd == CMD_BACKLIGHT_OFF:
            for bl, n in zip(bl_strips, BACKLIGHT_LED_COUNTS):
                for j in range(n):
                    bl[j] = (0, 0, 0)
                bl.write()
            continue

        if cmd == CMD_OTA:
            # 2 B długość (big-endian), potem body – zapis do main.py i reboot
            len_buf = b""
            deadline = time.ticks_add(time.ticks_ms(), 100)
            while len(len_buf) < 2 and time.ticks_diff(deadline, time.ticks_ms()) > 0:
                chunk = uart.read(2 - len(len_buf))
                if chunk:
                    len_buf += chunk
                if len(len_buf) < 2:
                    time.sleep_ms(2)
            if len(len_buf) >= 2:
                L = (len_buf[0] << 8) | len_buf[1]
                if 0 < L <= OTA_MAX_SIZE:
                    body = b""
                    deadline = time.ticks_add(time.ticks_ms(), 30000)
                    while len(body) < L and time.ticks_diff(deadline, time.ticks_ms()) > 0:
                        chunk = uart.read(min(256, L - len(body)))
                        if chunk:
                            body += chunk
                        if len(body) < L:
                            time.sleep_ms(2)
                    if len(body) >= L:
                        try:
                            f = open("main.py", "wb")
                            f.write(body[:L])
                            f.close()
                            soft_reset()
                        except Exception:
                            pass
            continue

main()
